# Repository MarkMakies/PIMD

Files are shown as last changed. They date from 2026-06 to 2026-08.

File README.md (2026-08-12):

# PIMD — Pulse Induction Metal Detector

*A from-scratch, multi-band pulse-induction metal detector built for autonomous, position-tagged ground survey.*

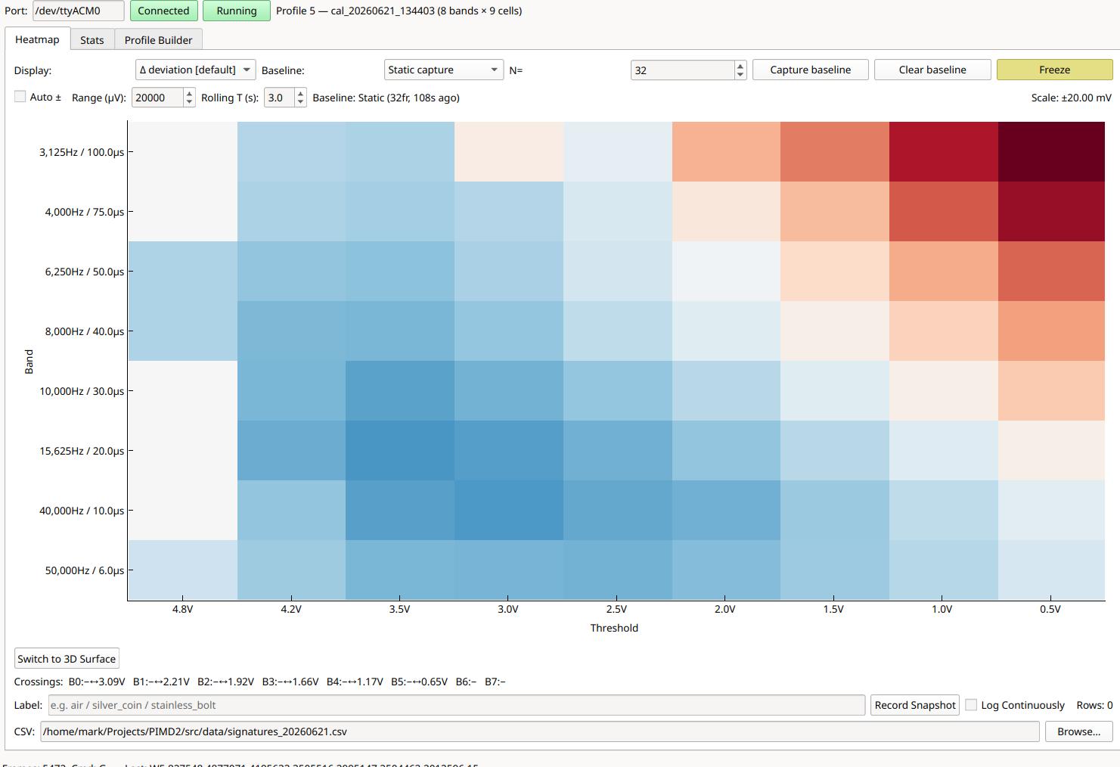
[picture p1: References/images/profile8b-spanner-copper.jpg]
Mixed ferrous + non-ferrous target — the 8×9 decay-space matrix splits into non-ferrous (blue, early decay) and ferrous (red, late decay)


> Above: a single live frame with a steel spanner **and** a copper pipe under the coil. The two
> materials separate *spatially* inside the decay-space matrix — non-ferrous (blue) collapses early,
> ferrous (red) persists late. Getting that separation out of a pulse-induction detector is the whole point.

**Up to date Build diary:** <https://makies.com.au/pulse-induction-metal-detector/>

---

## What it is

A pulse-induction (PI) metal detector designed and built from scratch since November 2023 by a maker
with no prior analogue-electronics background. It is **not** a clone — several design choices are
deliberately unconventional.

In the language of the field, it's a **low-cost, monostatic time-domain electromagnetic (TEM)
spectrometer doing cued interrogation** — though it started life as nothing more ambitious than
"let's build a metal detector with no experience." It is one payload of a larger system: the coil is
towed on a trailer behind **Roverling**, an autonomous RTK-GPS ground robot, so every detection event
can be tagged with centimetre-level position and streamed back over LoRa. It therefore has to be
*quiet, stable and remotely controllable*, not merely sensitive.

What makes it unusual among PI detectors is that it doesn't optimise a single operating point.
It cycles through a user-defined grid of operating points and reports, for every frame, a
two-dimensional **decay-space matrix** — frequency/pulse-width on one axis, decay-amplitude (time) on
the other — that is designed from the ground up as an input to a classifier.

## How it works (in brief)

A high-current pulse energises the TX coil; on hard cutoff the collapsing field produces a flyback
and then a decaying eddy-current response. A nearby target perturbs that decay. The conditioned RX
signal is sampled at precise, calibrated delays.

- **Mode 1** — a single filtered (32-bit) sample at one held delay: the low-noise telemetry path, used for baselines and field tests.
- **Mode 2** — an interleaved sweep across a profile of *(frequency, pulse-width, sample-delay)* points, reported as one frame per sweep. The grid is not fixed by the hardware, and it has deliberately *narrowed* as the corpus taught which cells earn their place. The July 2026 signature corpus was captured on a **63-cell** grid (7 pulse widths × 9 delays, spaced geometrically 9 → 100 µs at ×1.5 per step). The **current profile, `cal_2x11_v5`, runs 2 pulse widths (10 and 100 µs) × 11 sample delays = a 22-cell matrix**, sweeping at **16.1 Hz** *(measured)* — ~30% faster frames for the loss of the redundant middle bands. It is **not yet locked and has no corpus behind it**. Repetition rates are chosen to hold duty near 30%; the 100 µs band runs at 3.125 kHz and **requires the cooling fan** (see Hardware).
- Sample delays use **two anchoring schemes in one profile**, where a PI profile conventionally picks one. Early cells are **amplitude-anchored** to a ladder of voltages (**2.4 V → 125 mV**) high on the flyback decay rather than the usual bottom ~700 mV — that region carries the most discrimination information, and it is where target *polarity* separates the families. Late cells are **time-anchored** on a geometric ladder out along the tail, because past the front end's lobe both families read positive and only *decay rate* separates them. Every delay is snapped to the 8 ns PWM grid (off-grid requests are silently rounded by the hardware). The profile spans the decay from 2.4 V down to the ~110 mV pedestal with no gaps — the null minimum is sampled deliberately, not avoided.
- **Polarity convention:** ferrous targets read **positive** (stored magnetic energy reinforces the decay); non-ferrous read **negative** (opposing eddy currents weaken it). A third class turns out to be common in practice: **crossover targets** (cast iron, some stainless, real jewelry with steel fittings) read negative at short pulses and positive at long ones — the pulse-width axis resolves what a single operating point would misclassify.

## Highlights

- A multi-band decay-space matrix recovering **multi-time-constant discrimination from a PI platform** — something most commercial PI detectors don't attempt.
- **Validated on a 17-target labelled corpus** (July 2026): signature *shape* is invariant with target distance (5–15 cm, 30× amplitude range) and repeats across sessions and recalibrations to within a few percent — the property the classification layer is built on.
- Targets fall into **three shape families** — ferrous, non-ferrous, and crossover — and overlapping targets combine **linearly** (a spanner + copper pipe frame decomposes back into its parts at 0.99 correlation), so unmixing is on the table, not just classification.
- Phase-locked TX/sample timing on one RP2040 PWM slice — **~5 ns sample-trigger jitter (measured)**.
- LTC2508-32 dual-output front end (filtered 32-bit + raw 14-bit no-latency).
- A dedicated delay-calibration tool that measures the clip-release point per band and exports calibrated profiles.
- Three PyQt6 desktop tools: live Mode 1 GUI, the Mode 2 heatmap + ML-data bridge (`ClassViz`, including a self-describing session recorder for training data), and the delay calibrator.
- Built for autonomous use: RTK-GPS position tagging, LoRa telemetry, single dedicated low-noise supply.

## Repository layout

```
README.md                  This file — start here
DESIGN.md                  Full engineering reference (hardware, firmware, protocol, test log)
CHANGELOG.md               Project change log
CLAUDE.md                  Contributor / agent conventions (version bumps, changelog discipline)

mcu/                       MicroPython firmware for the RP2040-Zero
  pimd_mcu.py  main.py

src/                       PC-side tools (PyQt6)
  pimd_gui.py              Mode 1 filtered-telemetry GUI
  pimd_classviz.py         Mode 2 decay-space heatmap + ML logger
  pimd_delaycal.py         Delay-calibration sweep tool
  pimd_rawlog.py           Raw Mode 2 session logger
  pimd_pack.py             Shared 6S pack fuel-gauge maths (imported by the four GUI apps)
  pimd_shape.py            Shared feature maths (family / crossing / decay persistence)
  pimd_features.py         Training-corpus builder
  pimd_target_check.py     Target-registry validator
  pimd_corpus_check.py     Corpus-level acceptance checker
  requirements.txt
  data/                    Settings, captured CSVs and calibrated profiles (runtime-generated)

Electronics/PIMD604/       KiCad project — schematic rev 6.04 (as-built)

References/                Schematic export, scope captures, sample heatmaps
```

## Toolchain & workflow

The firmware is the measurement primitive; every PC tool is a client of the same USB-serial
protocol (`DESIGN.md` §9). Together they form one pipeline:

```
mcu/pimd_mcu.py (RP2040)            — the measurement primitive
      │  USB-serial, ASCII records (DESIGN §9)
      ├─► src/pimd_delaycal.py      — calibrates sample delays,
      │        exports cal_*.json profiles ──► src/data/profiles/
      ├─► src/pimd_gui.py           — Mode 1 live telemetry / bench monitor
      ├─► src/pimd_rawlog.py        — verbatim Mode 2 session logger (ground truth)
      └─► src/pimd_classviz.py      — Mode 2 heatmap; loads & runs saved profiles;
               │    captures signatures ──► src/data/corpora/ + src/data/sessions/
               └─ uses src/pimd_shape.py — shared feature maths
                            │
                            ▼
          src/pimd_features.py + src/pimd_target_check.py
               — registry-validated training-corpus builder ──► ML corpus
```

`pimd_pack.py` is shared by all four GUI apps, so they can never disagree about the same battery.

**Typical workflow**

1. Flash the firmware once (`DESIGN.md` §16).
2. Run **delaycal** after a full thermal soak to produce a calibrated profile; lock the profile JSON.
3. Run **classviz**, *Load & Run* the locked profile, and capture target signatures against the
   target registry in `src/data/targets/`.
4. Build the corpus with **features**; gate a capture day with **corpus_check**.

**gui** is the independent Mode 1 bench monitor used for noise-floor and drift investigation at a
single operating point. **rawlog** is the deliberately dumb recorder: it writes every line the
firmware sends, verbatim, so there is always a raw record no display logic can corrupt. Never run
Mode 1 and Mode 2 at once — always send `E` between mode switches.

> Each tool carries its own detailed operating notes — intent, wire commands used, record formats
> and per-version lineage — in its **file header**, which is updated in the same edit that changes
> the behaviour. Current firmware and tool versions, and the operating profile in use, are on the
> header line at the top of **`DESIGN.md`**; they are deliberately not duplicated here.

## Quick start

No build step for either the PC tools or the firmware.

### PC tools

```bash
python3 -m venv .venv && source .venv/bin/activate
pip install -r src/requirements.txt
cd src
python pimd_gui.py        # Mode 1 GUI (filtered telemetry)
python pimd_classviz.py   # Mode 2 decay-space visualiser + ML bridge
python pimd_delaycal.py   # delay-calibration sweep
```

The tools connect to the board on `/dev/ttyACMx` at 115200 baud.

### Firmware

```bash
# No build step — copy onto the board, then power-cycle it.
.venv/bin/mpremote connect /dev/ttyACM0 fs cp mcu/pimd_mcu.py :pimd_mcu.py + fs cp mcu/main.py :main.py
# (mpremote reset does not re-enumerate USB reliably — power-cycle the board.)
.venv/bin/mpremote connect /dev/ttyACM0 repl
```

### Bench-test over a serial terminal (115200)

```
V                              identify / firmware version
L                              list profiles
Q5   then  G                   Mode 2: stream the loaded operating profile (W5 records);  E to stop
*5000,40000,8400,256  then S   Mode 1: stream (* records, ~20/s);  E to stop
A32                            one 32-sample boxcar average (R record)
```

> Protocol note (firmware v4.23+): the `*` command takes **freq in Hz, pulse/delay in ns**; the `D`
> dynamic-profile command takes **µs**. See `DESIGN.md` §9 for the full contract.

## Hardware

- **Schematic:** the published KiCad project is **rev 6.04**, which represents the board **as-built**. The PCB itself was fabricated from rev **6.01**; 6.04 captures the corrections — there were a few PCB issues that needed rectifying after manufacture.
- **Front end / drive:** functional but a known rework target — a future revision will replace the TX switch and gate driver (planned: STP10NM60N + TC4420/TC4429) to retire the current FET being run past its rated SOA.
- **Thermal:** a thermistor is now fitted to the TX damping resistor. Thermal drift settles to effectively zero once the resistor reaches ~80 °C, which is the dominant warm-up transient.

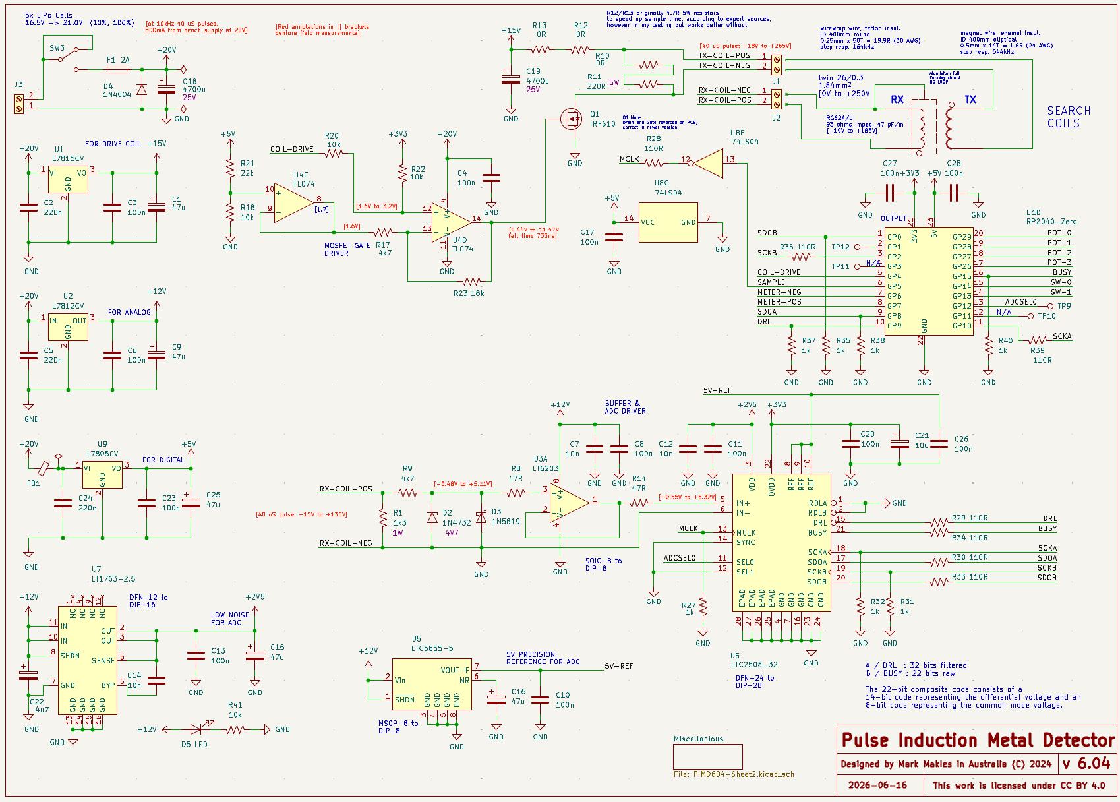
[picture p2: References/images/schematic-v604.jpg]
Schematic — PIMD rev 6.04


## Roadmap

This release is **Phase 2 — publish the work to date.** Active and planned work:

- **Phase 3 — machine learning.** Use the decay-space matrix for filtering, classification and (the stretch goal) ground discrimination. First milestone reached (July 2026): a locked, delay-calibrated operating profile and a 17-target labelled signature corpus recorded at three distances, with distance-invariance, cross-session repeatability and mixture linearity all verified in air.
- **Faster response.** First cut made (August 2026): 63 cells → 22, for ~30% faster sweeps. Because the corpus says different targets go redundant in *different* cells, the narrowed grid has to earn its keep against a fresh corpus before it can be locked — that re-validation is the open work, along with per-cell averaging.
- **Front-end revision** (TX switch + gate driver, as above), plus a scope measurement of TX coil current vs pulse width to settle whether the longest band is past the coil-current plateau.

See **DESIGN.md §14** for the full open-problems list.

## Documentation

- **[DESIGN.md](DESIGN.md)** — the complete engineering reference: measured operating envelope, coils, drive and receive chains, timing, serial protocol, power, invariants and curated test log. Self-contained; a new reader (human or agent) can pick up the project cold from it.
- **Per-app notes** — each tool's intent, operation, wire commands and version lineage live in its own **file header** (`mcu/pimd_mcu.py`, `src/pimd_*.py`); the pipeline that connects them is under *Toolchain & workflow* above.
- **Build diary** — the full chronological story, with photos and dead-ends: <https://makies.com.au/pulse-induction-metal-detector/>
- **Video** — <https://www.youtube.com/@markmakies>

## Licence

This project uses two licences, matched to the kind of work:

- **Code** (`src/`, `mcu/`) — **GNU GPL v3.0-or-later**. See [`LICENSE`](LICENSE).
- **Hardware and documentation** (`Electronics/`, `DESIGN.md`, schematics, images) — **Creative Commons Attribution-ShareAlike 4.0 (CC BY-SA 4.0)**. See [`LICENSE-docs`](LICENSE-docs).

Pulse Induction Metal Detector © 2022–2026 Mark Makies.

## Author

Built by **Mark Makies** (Australia).
Find more work at <https://makies.au/>.

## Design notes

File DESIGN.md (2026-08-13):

# Pulse Induction Metal Detector (PIMD) 

**Author:** Mark Makies (Australia) · **Licence:** CC BY-SA 4.0
**Hardware rev:** 6.04 + shielded enclosure (2026-07-13) + 6S Li-ion supply (2026-07-24) + pack-voltage sense & DS18B20 board temperature (2026-08-07) + **RX front-end +97 mV bias (2026-08-10)** + **U1 L7815CV replaced 2026-08-10 (failed; like-for-like on a larger heatsink)** + **6S pack replaced 2026-08-13 (new balanced cells, same ICR18650-26C arrangement)** + **40 mm 24 V case-mounted extractor fan over the FET / regulator / load-resistor cluster — permanent, pack-fed through the rig's own switch and a fuse, fitted 2026-08-13; supersedes the 38 mm blow-on fan** + **USB and power toroids removed, power cable shortened 27 cm (2026-08-13)** + **C18 2200 µF 35 V fitted 2026-08-14 (was 4700 µF 25 V — voltage derating, not capacitance; C19 assessed and left at 4700 µF 25 V)** · **Firmware:** v4.37 · **PC tools:** gui v4.18 · classviz v1.79 · delaycal v1.49 · rawlog v1.17 · pack v1 · features v15 · shape v1 · target_check v4 · corpus_check v1.10 · **Coil:** v4 · **Operating profile:** `cal_2x11_v5d` (2026-08-13, 2 × 11 = 22 cells, `profile_sha8` **fc7519cd**, **locked and fully measured — no corpus yet**). Bump this line on every edit.
**Last bench update:** 2026-08-13 (40 mm extractor validated — 97.6 min of pulsing over four sessions, 104 618 sweeps, zero flagged rows)
**Doc rev:** 2.9 (2026-08-14) mini consolidation pass (§18), scoped to the C18 refit. **§14.2 (C18 under-rated) is closed** — the 2200 µF 35 V part is fitted, and its "candidate contributor to the 2026-08-10 U1 failure" line is withdrawn as never evidence-backed (`CHANGELOG.md` carries the withdrawal and a better-supported explanation; do not revive it). The schematic-mismatch item renumbers to **§14.2** and gains a third instance for C18, so it is no longer confined to the RX front end; §7 and §15's `§14.3` cross-refs follow it. §14 is down to **two** open problems. Also new in `CHANGELOG.md`, deliberately not promoted here because it is calculated rather than measured: **TX inductance has never been measured**, and the C18/C19 sizing rests on an inferred ≈200 µH. No firmware or tool version changed (2.8)

> This file is self-contained: a new reader — human or AI agent — should be able to pick up the
> project cold from here alone. Empirically measured values are marked *(measured)*; everything
> else is nominal or design intent. **Detail, rationale and history live in `CHANGELOG.md`** —
> if you want to know *why* something is the way it is, search there, not here.

---

## 1. What this is, and current status

A pulse-induction (PI) metal detector designed and built from scratch since November 2023 by a
maker with no prior analogue-electronics background. It is not a clone; several choices are
deliberately unconventional.

The detector is one payload of a larger system: it is towed on a trailer behind **Roverling**, an
autonomous RTK-GPS ground robot, so detection events can be tagged with centimetre-level position
and streamed over LoRa. It therefore has to be quiet, stable and remotely controllable, not merely
sensitive.

**Status — working and field tested.** It discriminates ferrous from
non-ferrous targets in real soil, reliably to ~20 cm before the noise floor dominates.
**Mode 1 (filtered)** is mature and was used for all baselines and field tests. **Mode 2 (raw
profile sweep)** — the decay-curve — is operational and is where all current work
sits. 

---

## 2. Operating principle

A short, high-current pulse is driven through the TX coil, building a magnetic field. The drive FET
is switched off hard; the collapsing field induces a large flyback then a decaying eddy-current
response. A nearby metal target sustains its own eddy currents, perturbing the decay. Sampling the
RX-coil voltage at a precise short delay after turn-off and comparing to a baseline reveals the
target's presence and type. **Turn-off speed and sample-timing precision set the floor on what can
be detected.**

**Target polarity (measured convention):** ferrous → **positive** spike (stored magnetic energy
reinforces the decay field); non-ferrous → **negative** spike (opposing eddy currents weaken it).

**1 — Early: polarity.** Before the front end's negative lobe, sign splits the families. On the
100 µs band that window is **sd 7.97–12.30 µs**, widest at 9.57 µs — steel **+46.5 mV**, copper
**−74.4 mV** against air.  The crossing where a non-ferrous target stops reading negative and starts
reading positive **marches earlier with shorter pulse** — brass crosses at **~12.3 µs** on the 50 µs 
band and **~11.7 µs** on the 10 µs.

**2 — Through the null.** **Both families read positive against air**,
because air is the thing that dips and both targets fill the dip in. Sign is useless there; depth
is the measurement. 

**3 — Late: decay rate.** Out on the pedestal both families read positive and only decay rate
separates them (copper outlasts steel, crossing at ~44 µs on the coil and ~77 µs at 60 mm — the
crossover moves with coupling). A ferrous target adds a genuine **second, slow pole** of its own
that air and non-ferrous do not have.

---

## 3. Measured operating envelope (updated 2026-08-13)

- **Flyback** *(measured, 10 kHz / 40 µs)*: TX coil **−18 V to +265 V**, RX coil
  **−15 V to +135 V**. Gate turn-off **11.47 V → 0.44 V in 733 ns**.
- **FET Q1 limits:** < 10 A, < 300 µs, < 2 % duty. The detector runs above the duty limit and needs redesign.
- **RX front-end node** after R9: **−0.48 / +5.11 V**; ADC input settles
  **~5.0 V**; edge ring peaks **+5.30 / −0.69 V** (brief, current-limited, harmless).
- **Post-bias, air never goes below 67.2 mV** *(measured 2026-08-10, worst case = 100 µs band)*
  against the amplifier's 2.441 mV output floor, all three bands, now has ≥ 65 mV of headroom underneath it.
- **Sample-timing precision** ≈ **5 ns** *(measured)*.
- **Thermal drift** ≈ **−50 µV/s** at 10 kHz / 20 µs *(measured)*. 
- **Noise floor ≈ 38 µV** *(measured 2026-08-13, `cal_2x11_v5`, 32 × 256 averaging, detrended
  32-sweep σ, 40 mm extractor)* — flat across every null/pedestal cell and **independent of delay**,
  i.e. **~64× below** the 2.441 mV amplifier output floor. Band 0's largest cell remains ~2× noisier
  than band 1's at the same amplitude (70 vs 36 ppm raw) — still unexplained, but improved from
  93 vs 38. Noise does **not** rise as the pack falls. *(Supersedes ≈ 65 µV / 93 vs 38 ppm, which
  was the same statistic on the 38 mm blow-on fan — that figure is epoch-bound to ≤ 2026-08-12.)*
- **Run-to-run repeatability** *(measured 2026-08-13)*: the settled band-0 operating point reproduces
  to **0.06 %** across independent cold starts, and bucket-to-bucket noise scatter is **2.2 µV**
  against 6.4 µV on the 38 mm rig.
- **Warm-up from cold: allow 6 min** *(measured 2026-08-13, 40 mm extractor, two independent cold
  starts)*. Band-0 mean settles as a **clean single exponential**, τ = **1.15 / 0.90 min**
  (r² = 0.982 / 0.988), within **0.2 % at 5.6 / 3.8 min**. The DS18B20 still reaches its final
  reading well before the signal settles and **is not a readiness indicator**. *(Supersedes the
  10 min / τ = 2.15 min figure, epoch-bound to the 38 mm fan, where warm-up was **two-stage** — a
  fast drop then a slow case-soak still drifting at 20–25 min. Continuous bulk air exchange
  suppresses the slow stage; that shape change is the mechanism.)*
- **Standard Operating Conditions:** Mode 1 · 10.0 kHz / 20.0 µs pulse / 10.0 µs delay /
  DS 256 · coil in air, no targets. Reference capture:
  `References/images/GUI-steady-state-256-1024.jpg`.
- **Board temperature moves the operating point — but the DS18B20 does not predict it** *(measured
  2026-08-12)*. At the **same indicated 44.1 °C** band-0 mean read 543.8 and 533.9 mV five minutes
  apart: **1.8 % spread at identical sensor temperature**. Bulk warm-up and airflow changes move
  band 0 in **opposite directions** against the same sensor — nudging the fan off the U1/FET cluster
  took the sensor 41.0 → 46.0 °C and band 0 **+3.7 %**, where warm-up over that span moves it down.
  A single µV/°C referred to this sensor is therefore **not well defined**. Which component dominates
  is **not determinable from the logs** — it needs a thermocouple on U1/Q1.
- **The fan mount was measurement-critical — resolved 2026-08-13 by the permanent case mount.** On
  the loose 38 mm fan a slight nudge was worth **3.7 % on band 0**, more than the entire discharge
  range. The 3.7 % still stands as the measure of how hard cooling moves the operating point (and
  is what 17.14's sign test detects), but fan geometry is now a fixed property of the build and no
  longer a variable to control.
- **The DS18B20 reads ~8 °C hotter on the extractor** — plateau **47.8 °C** against **39.8 °C** on
  the 38 mm blow-on, from comparable cold starts, because the sensor sits on the load resistor and
  has lost the old fan's direct impingement. **Board temperatures either side of 2026-08-13 are
  different quantities and must not be compared.** It remains blind to the regulator die.
- **State of charge barely reaches the operating point** *(measured 2026-08-12, at flat board
  temperature, two windows spanning 23.05 → 19.07 V)*: **~1 mV/V grid mean** (0.17–0.23 %/V), one
  sign. Total movement across a full 2.1 V discharge window is **−0.69 %** grid mean / −0.81 % band 0
  / −0.54 % band 1. **Thermal drift dominates supply drift by ~10×.**
- **Full-scale headroom:** the coldest capture of 2026-08-12 was **3633 mV at 19.5 °C** on a full
  pack — the day's maximum on any cell, **1367 mV (27 %) below** the 5.000 V full scale. Nothing
  railed or floored in 3.1 h of pulsing. **Untested below 19 °C.**

---

## 4. System block diagram (text)

```
 6S Li-ion (19.8–25.2 V, working floor 19.0 V)
        │  F1 2A ─ D4 reverse-prot ─ FB1 ──► `+20V` rail (raw pack, after fuse + toroid — feeds
        │                                     the three linear regs below and GPIO26's divider)
        ├── U1 L7815CV ──► +15 V  (coil drive rail)
        ├── U2 L7812CV ──► +12 V  (analogue rail)
        ├── U9 L7805CV ──► +5 V   (digital) ──► RP2040 onboard LDO ──► +3V3
        └── U7 LT1762-2.5 ──► +2V5 (ADC)        U5 LTC6655-5 ──► +5V precision ref

 RP2040-Zero (U10)
   GPIO4  PWM2A ─ COIL-DRIVE ─► U4C/U4D gate driver ─► Q1 (IRF610) ─► TX coil
   GPIO5  PWM2B ─ SAMPLE/MCLK ───────────────────────────► LTC2508 conversion start
   (GPIO4 & GPIO5 share PWM slice 2 → phase-locked TX pulse & sample trigger)
   GPIO26 pack-voltage sense (22k/2.7k divider)   GPIO6 DS18B20 board temperature

 TX coil ──(flyback, resistive damping ~220R)
 RX coil ─► R1 damp (1.5k‖10k=1304Ω) ║ R9 4.7k series ─► clamp (D2 4.7V zener + D3 1N5819) ─► 47R
          ─► LT6203 preamp/ADC driver (U3, single +12V) ─► LTC2508-32 ADC (U6)
          ─SPI─► RP2040
                       SDOA/SCKA/DRL  = 32-bit filtered/decimated  (SPI1, Mode 1)
                       SDOB/SCKB/BUSY = no-latency raw 14-bit       (SPI0, Mode 2)

 RP2040 ─ serial (USB-CDC / UART) ─► PC tools (PyQt6)
```

---

## 5. Coils

Separate TX and RX windings (a two-winding "transformer", **not** a shared mono coil).

**Coil v4:** both coils slotted into 12 mm Perspex, RX shielded with copper tape, both embedded for
mechanical stability (earlier coils shifted under rover vibration and drifted). Faraday shield on
RX with **no closed loop**.

- **TX** 520 × 360 mm, 10 turns 0.5 mm (24 AWG) enamelled, **17.6 m**, 1.7 Ω
- **RX** 430 × 265 mm, 50 turns 0.25 mm (30 AWG) Teflon silver-plated wire-wrap, **≈ 69.5 m**,
  22.9 Ω
- Cable: RG62A/U coax (93 Ω, 47 pF/ft) + twin 26/0.3

**Damping is intentionally biased toward over-damping** — it kills ring faster and lets sampling
start earlier, trading a little amplitude for earlier access to the decay. Tuned empirically on a
scope, not by formula.

---

## 6. Transmit / drive chain

- **Q1:** IRF610 N-channel MOSFET, low-side switch, source to GND. Schematic limits < 10 A /
  < 300 µs / < 2 % duty; the 200 V rating is marginal against measured flyback and is managed by
  duty limits + damping (§14.1).
- **Gate driver:** U4C → U4D (TL074 sections) level-shift the 3.3 V `COIL-DRIVE` logic to a ~10 V
  gate swing. Design intent: fast, non-linear FET switching with parasitic-capacitance management.
- **Gate / damping network:** R12/R13 are now **0 Ω** (originally 4.7 Ω 5 W to slow the gate edge
  for SOA; this build performs better without them).
- **Turn-off** *(measured, 10 kHz / 40 µs)*: gate **11.47 V → 0.44 V in 733 ns**.

---

## 7. Receive / acquisition chain

### RX front end (schematic v6.04)

```
RX coil ─┬─ R1 ─ GND                   (shunt = damping; AS BUILT 1.5k ‖ 10k = 1304Ω,
         │                              schematic v6.04 still draws a single 1.3k — §14.2)
         └─ R9 4.7k ──┬─ D2 1N4732 (4.7V zener) ─┐  (positive clamp)
                      │  D3 1N5819 (Schottky) ───┘  (negative clamp)
                      └─ 47R ─┬─► U3A LT6203 +input, pin 3 (single +12V supply)
                              │
    U5 pin 7 (5V-REF) ─[240k 1% metal film]─┘   +97 mV bias — fitted 2026-08-10, NOT on the
                                                schematic (§14.2)
```

- **R1 (shunt) is the RX damping resistor**, which also cleans up TX via mutual coupling.
   **As built it is TWO resistors in parallel, and the schematic does not show this**:
  **1.5 kΩ ∥ 10 kΩ**  **1304 Ω effective**. Schematic v6.04 still draws a single `R1 1.3k`. 
  By that fit the network sits at **ζ = 1.06 — just into over-damping**, which is the intent.
- **R9 = 4.7k (series) is clamp current-limit only**, not damping.
- **D2 / D3** sit in series across the post-R9 node and conduct only outside ~0–5 V; between the
  rails the diodes are off and R1 does the damping.
- **47 Ω** between LT6203 output and ADC input limits over-range current into the ADC's protection.

### Preamp / ADC / references

- **U3 LT6203** dual high-speed op-amp, single +12 V.
- **U6 LTC2508-32**, 32-bit oversampling SAR with a configurable decimation filter **and** a
  no-latency raw output:
  - **SDOA (SPI1):** 32-bit filtered/decimated, `DRL` data-ready-low — the precision path.
  - **SDOB (SPI0):** no-latency raw 14-bit the acquisition path.
  - **Decimation** SEL0 (GPIO12): 256 (operating) or 1024.
  - **Conversion sync:** the falling edge of GPIO5 (`SAMPLE`/`MCLK`) starts each conversion, so
    every TX cycle yields one timed sample at exactly `sample_delay` after coil turn-off.
- **References:** U5 LTC6655-5 (precision 5 V), U7 LT1762-2.5 (low-noise 2.5 V for ADC).

### Acquisition architecture (decided)

Use the **raw no-latency path (SDOB)**, not the filtered one. At 5 kHz the filtered path has
≈ 0.46 s group delay, ≈ 0.5 s settling after any delay change and only ≈ 2.4 Hz bandwidth —
unusable for sweeping the sample point. Recover resolution by **boxcar-averaging M raw samples at a
held delay** (noise ∝ 1/√M; M = 16 ≈ 350 µV in ~3.2 ms, matching the filtered path's real-world
450 µV floor). The 32-bit precision is otherwise wasted: measured noise is ~500× the converter's
own 0.95 µV floor — **the front end dominates.**

**BUSY edge sync is required for accurate SDOB reads** : wait for BUSY-high (conversion
starts), then BUSY-low (complete), then read SDOB. Without it, reads landing mid-conversion produce
bit-truncated outliers at exactly **1/4 and 1/2** of the true value. Side effect: the BUSY-high
pulse at 10 kHz is ≈ 15 µs and MicroPython's polling loop catches ≈ 1-in-6, reducing effective raw
sample rate to ≈ 1.6 kHz. Accepted trade for accuracy.

**Clip-release** — the instant the conditioned signal leaves the clamp rail (~4.7 V) and enters the
linear 0–5 V window — is the true earliest-valid sample time. `pimd_delaycal.py` measures it
directly.

### The front-end transient — measured at the amplifier input

**Shape — from the 2026-08-08 fit, and the shape is what survives:**

- **Two real poles with opposite-sign residues**, `V = A·e^(−t/τf) − B·e^(−t/τs) + V_q`:
  **τ_fast = 1.125 µs, τ_slow = 2.270 µs** *(measured)*, fit RMS 0.87 mV over 894 points. Exactly
  **one zero crossing** — it is not ringing.
- **ζ = 1.06 — mildly over-damped**, not critically damped. 
- **The negative lobe is real, it is in air, and it is on every band.** It is **not** amplifier
  overload recovery: it is present *before* the LT6203, and it **responds to metal** — a steel
  spanner on the coil removes the zero crossing entirely (minimum +15.5 mV, difference up to
  +48.9 mV). 

### The +97 mV bias mod — built and characterised *(2026-08-10)*

**The problem it solves.** U3A is a unity-gain follower on a single +12 V rail and its output cannot
go below **2.441 mV**, so air's excursion below quiescent was clipped flat. 

**The fix is one resistor** 240 k 1 % metal film from U5 pin 7
(5V-REF) to U3A pin 3. Pin 3's DC path to ground is `R8 + R9 + RX coil` ≈ **4.77 kΩ** (the coil's
19.9 Ω shorts out R1, so R1 barely features), giving 5.0 × 4770/244770 = **97.4 mV**. Taken from
5V-REF rather than +5 V or +12 V so that offset and full scale drift together and the code does not
move. Signal-node loading is **1.9 %**.

### Target decay — model fits over the measured window *(2026-08-10, fitted in log space)*

**Air and brass need only a single repeated pole** — the free two-pole fit drives τ_fast → τ_slow,
and `(P + Q·t)·e^(−t/τ)` fits identically well. **Steel on the two long bands needs a genuine
second, slow pole, and that is the target's own eddy decay:**

| band | air | brass | steel |
|---|---|---|---|
| 100 µs | τ 1.96 µs · ±5.6 mV | τ 1.79 µs · ±8.5 mV | τf 1.24, **τs 19.0 µs** · ±6.0 mV |
| 50 µs | τ 1.89 µs · ±6.8 mV | τ 1.77 µs · ±8.4 mV | τf 1.18, **τs 23.4 µs** · ±8.7 mV |
| 10 µs | τ 1.78 µs · ±13.4 mV | τ 1.76 µs · ±13.2 mV | τ 1.67 µs · ±12.4 mV |

**The slow pole appears only with a ferrous target and vanishes on the 10 µs band** — a 10 µs pulse
barely excites it. Independently corroborated by the fill fractions, where steel filled only 62 % of
the null at 10 µs against 100 % on both long bands (§2). *Caveat on the fast pole: every capture
starts at ~9–12 µs, so a ~1.2 µs pole is far outside the data and **τ_fast is not independently
identifiable here** — treat it as a fitted shape parameter, not a measurement.*
`References/images/bias_mod_delay_plot_20260810.png` overlays these fits on the traces.

### RX L and C — pinned *(2026-08-08)*

**ζ is the one number here that does not depend on R at all.** For a parallel RLC the two fitted
poles alone fix it:

> **ζ = (τ_f + τ_s) / (2 √(τ_f · τ_s)) = 1.0622**

Taking the fitted poles with R1 = 1300 Ω gives **C = 579 pF**, **L = 4.41 mH**, √(L/C) = 2762 Ω and
**R_crit = ½√(L/C) = 1381 Ω**. 

**Substitution sensitivity** — what happens if R1 is *changed*, holding the fitted L and C. Damping
is a **shunt**, so **lower R means more damping**. (Unlike ζ above, this table inherits the R = 1300
assumption through L and C, so read it as a guide to picking a resistor, not as a measurement.)

| R1 | ζ | |
|---|---|---|
| 1239 Ω — as-built pair, −5 % corner | 1.11 | over-damped |
| **1304 Ω — as built, nominal (1.5k ∥ 10k)** | **1.06** | **over-damped, the intent** |
| 1370 Ω — as-built pair, +5 % corner | **1.01** | over-damped, but **effectively critical** |
| 1380 Ω | 1.00 | critical |
| 1400 Ω | 0.99 | under-damped — ring returns |

**These values rest on the 2026-08-08 scope fit alone** — 894 points, residual RMS 0.87 mV, taken
at the amplifier input on the current hardware. 

---

## 8. Digital / timing (RP2040)

- **MCU:** Waveshare RP2040-Zero (U10), MicroPython. Firmware `mcu/pimd_mcu.py` **v4.37**.
- **Pulse + sample generation:** two PWM channels on the **same slice** (GPIO4 = PWM2A drive,
  GPIO5 = PWM2B sample). Same slice ⇒ both rising edges align at period start; drive falls at
  `pulse_width`, sample falls at `pulse_width + sample_delay`. **This phase-locking is the core
  timing mechanism — never split these onto different slices**. Timing precision ≈ 5 ns
  *(measured)*.
- **Pulse width** 5–100 µs typical. **Sample delay** software-set, with an
  empirical `SAMPLE_PULSE_CORRECTION = 0.904 µs` offset between the PWM edge and the ADC trigger.
  Every delay the hardware can produce is a multiple of the **8 ns PWM grid**; an off-grid request
  is silently rounded. **8 ns is also the hard minimum spacing between two cells** — the `dd`/`sd`
  CC-write skip means two cells closer than that collapse silently into one.
- **Pulse rate** 2–50 kHz. A **prime-ish** rate halved noise by avoiding beat frequencies — the
  choice is deliberate. **Known-bad rate: 31.25 kHz** 
- **Board temperature: DS18B20 on GP6.** 1-Wire, SKIP ROM, CRC-checked, 30 s cadence,
  3V3 normal 3-wire mode.
- **SPI map:** SPI0 raw (SCKB GPIO2 / SDOB GPIO0 / BUSY GPIO15); SPI1 filtered (SCKA GPIO10 /
  SDOA GPIO8 / DRL GPIO9); SEL0 = GPIO12.

---

## 9. Serial protocol (both modes) — the firmware↔tooling contract

Two **mutually exclusive** acquisition modes over one serial link (115200 baud). Starting one
requires `E` first. *(Literal field separator is `", "` — comma-space — shown comma-only below;
parsers tolerate either. All timing fields are exact integers: freq in Hz, pulse and delay in ns —
**except the `D` command below, whose `pulse` and per-cell delays are in µs.**)*

**Mode 1 — filtered / interrupt-driven** (mature; all baselines & field tests):
- **in:** `S`/`s` start · `E`/`e` stop · `*<freq_hz>,<pulse_ns>,<delay_ns>,<downsample>` configure
- **out:** `*<time_ms>,<value_uV>,<stddev_uV>,<freq_hz>,<pulse_ns>,<delay_ns>,<downsample>`
- **rate:** pulse_freq / downsample (~20/s at 5 kHz / 256)

**Mode 2 — raw interleaved moving-average sweep** (the active path):
- **in:** `Q<n>` select profile · `G`/`g` start streaming · `E`/`e` stop ·
  `D<avg>;<freq_hz>,<pulse_us>,<d0>,…;…` define the RAM-only dynamic profile (index 5).
  **`avg` is bounded 1..128**; the whole `D` is refused on any invalid cell, and a
  refused `D` leaves the previous dynamic profile live — **wait for `D OK`** (§8).
- **out:** `W<profile_idx>,<time_ms>,<mean_ch0>,<mean_ch1>,...`
- **rate:** one W record per full sweep, rate-limited to one per `MIN_EMIT_MS = 10` ms (never
  reached in practice). Each cell gets one PWM period per sweep, with a rolling average `averages`
  deep held *across* sweeps — so emitted rate **is** sweep rate. `S` is rejected while Mode 2 runs.

**Both modes:**
- `V`/`v`/`?` identify →
  `V<fw>,<board_id>,<num_profiles>,<active_idx>,<freq_hz>,<pulse_ns>,<delay_ns>,<downsample>,<pack_mV>,<board_temp_dC>,<lockout>`
  — **11 fields since v4.28**; the trailing three are sensor/lockout state. `board_temp_dC` is
  deci-degrees C and **`-32768` means NO READING**, never a temperature. **Consumers must treat the
  reply as extensible.**
- `P<time_ms>,<pack_mV>,<board_temp_dC>` — **unsolicited** sensor telemetry, ~60 s cadence
  *(v4.28+)*. **Parsers must anchor on a digit after `P`**: `PACK:` and `LOCKOUT:` are
  human-readable firmware messages on the same wire, and matching `P` alone swallows them.
- `L` list profiles → one `L<idx>,<freq_hz>,<n_bands>,<n_cells>,<averages>,<name>` per profile
- `A<n>` raw boxcar average (idle / Mode 1 only) →
  `R<time_ms>,<mean_uV>,<std_uV>,<count>,<freq_hz>,<pulse_ns>,<delay_ns>,<min_uV>,<max_uV>`
- `B` diagnostic counters, **reset-on-read** — **9 fields** →
  `B<busy_high_count>,<overrun_count>,<emit_block_count>,<emit_block_ms_max>,<gate_reject_count>,`
  `<gate_reprime_count>,<busy_timeout_count>,<busy_spin_min_left>,<rail_absent_ms_max>`. The last
  three arrived with the v4.37 rail-loss abort: `busy_timeout_count` says whether a rail loss
  happened at all, `busy_spin_min_left` is how close a *healthy* spin came to `BUSY_SPIN_LIMIT`
  (it resets to the limit, not to 0, so a small value means the cap is too tight), and
  `rail_absent_ms_max` is the longest rail-absent rest. No parser exists in `src/` — read by a
  human over a serial terminal.
  **The ratio is the number to read:** rejections with near-zero re-primes means the outlier gate is
  catching glitches, which is its job; re-primes climbing with the signal means it is fighting real
  signal and `OUTLIER_GATE_FRAC` is too tight for the profile in use (§8).
- `E` is the universal stop. Modes are mutually exclusive.

**µV scaling (invariant):** filtered (Mode 1) `raw32 * 5_000_000 // 2**31`; raw (Mode 2 / `A`)
`raw14 * 10_000_000 / 2**14`.

---

## 10. Scan profiles

Profiles are fixed/compiled-in or RAM constants (no flash writes). **Geometry is constant per
profile**.
**Frames from different profile geometries must never be mixed in one dataset.** An identical cell
count does *not* imply comparability — comparability rests entirely on the
`(profile_name, profile_sha8)` guard in `pimd_features`, **which must not be relaxed**.

### Operating profile — `cal_2x11_v5d` (2026-08-13)

#### cal_2x11_v5d — Cell / Zone / Delay / Anchor Table

`profile_sha8` **fc7519cd**. 2 bands × 11 cells (22 cells total), `averages` 32. **The sole profile
in use and the only file in `src/data/profiles/`** — v5, v5a and v5b were removed from the working
tree on 2026-08-13 and live in git history. **Locked, and every voltage in the table below is a
bench reading, not a target.** No corpus has been recorded against it yet.

**Sweep rate: 17.86 Hz** *(measured 2026-08-13, fw v4.37)*, against 12.45 Hz for the retired
`cal_3x10_v5` — **+43 %**. Unchanged across the v5a → v5b → v5d re-cuts, as expected: those moved
delays, never the band count, cell count or averaging depth. The run-length figures likewise carry
forward and are: **3.1 h bench-run on 2026-08-12, zero flagged rows in 63 813 uninterrupted
sweeps**, plus the 2026-08-13 extractor validation below.

**Runs at 3.125 kHz on the 100 µs band, and requires the cooling fan running.** Without the fan,
this band trips the +15 V regulator (U1) on a ~42 s cycle. The fan is powered from the rig's own
switch, so the requirement is **structural, not an operator step** — there is no state in which the
board pulses and the fan does not. **Validated 2026-08-13**: 104 618 sweeps over 97.6 min with zero
flagged rows, including a cold start at 24.48 V (worst U1 corner); the one run that ended did so on
the 19.0 V pack floor, not on heat.

| Cell | Zone | Delay µs (100 µs → 10 µs) | Anchor | Measured mV (100 µs / 10 µs) | Cross-band |
|---|---|---|---|---|---|
| 1 | Early | 9.456 → 6.496 | Amplitude — **4.700 V** | 4680.0 / 4696.0 | 0.34 % |
| 2 | Early | 11.392 → 8.376 | Amplitude — **1.900 V** | 1874.3 / 1898.5 | 1.28 % |
| 3 | Early | 12.136 → 9.088 | Amplitude — **1.150 V** | 1133.2 / 1151.0 | 1.56 % |
| 4 | Early | 13.248 → 10.176 | Amplitude — **0.500 V** | 498.9 / 499.4 | 0.09 % |
| 5 | Early | 15.088 → 11.960 | Amplitude — **0.125 V** | 123.0 / 124.2 | 0.91 % |
| 6 | Mid descent | 15.872 → 12.896 | Time-anchored, band-dependent | 79.0 / 77.9 | 1.32 % |
| 7 | Peak min | 16.920 → 13.800 | Null minimum (band-dependent depth) | 62.5 / 69.9 | 11.32 % |
| 8 | Rising | 21.160 → 16.160 | Rising out of null | 91.8 / 92.0 | 0.24 % |
| 9 | Late | 37.736 → 19.640 | Time-anchored — decay rate, not amplitude | 111.8 / 108.0 | 3.45 % |
| 10 | Late | 67.296 → 23.864 | Time-anchored — decay rate, not amplitude | 112.3 / 109.9 | 2.15 % |
| 11 | Late | 120.000 → 29.000 | Band's longest delay (10 µs band at hardware limit, 96 ns margin) | 112.0 / 111.0 | 0.93 % |

**Measured in air** *(2026-08-13, 1 666 sweeps over 93 s at steady state, zero flagged rows, pack
20.17 V, board 49.4 °C)*. Air std dev is 0.07–0.88 mV per cell on the 100 µs band and 0.05–0.23 mV
on the 10 µs. The cut sits near the **bottom** of the §12 clean window, so the anchors read higher
on a fuller pack — see **17.23**, and note its 2026-08-13 qualifier: the steep early anchors are far
more supply-sensitive than the grid mean. Cell 1 at 4.680 V is 94 % of the 5.000 V full scale and
wants watching at the top of the pack range.

**Zone breakdown:** 5 early / 1 mid descent / 1 peak min / 1 rising / 3 late — 11 cells total per band.

**Spacing is deliberately uneven.** Gaps across the amplitude anchors are 1.936 / 0.744 / 1.112 /
1.840 µs on the 100 µs band and 1.880 / 0.712 / 1.088 / 1.784 µs on the 10 µs — tight through the
knee where the target response turns over, wide either side. Even spacing has no claim here: the
decay is **not log-linear above ~2 V** *(measured 2026-08-13, both bands)*, so equal voltage ratios
are not equal time steps.

**Cross-band matching:** holds for cells 1–5 only (amplitude anchors), and is within 1.6 % on all
five. Cells 6–8 are null-region, band-dependent by construction — cell 7's 11.3 % is the null depth
differing by band, not a defect. Cells 9–11 are time-anchored.

**The null is sampled deliberately at its minimum** (cell 7) 

**`threshold_v` has MIXED MEANING in this profile.** Cells 1–5 carry the **real measured
amplitudes** (4.700 / 1.900 / 1.150 / 0.500 / 0.125 V) and are what `pimd_delaycal` keys its nudge
targets on. Cells 6–11 are **placeholder ordering keys only** (100 / 90 / 80 / 70 / 60 / 50 mV),
chosen solely to keep the column strictly descending. **Do not mine cells 6–11 as voltages** — the
null minimum measures 62.5 / 69.9 mV, not 90.

---

## 11. Invariants — do not break

- **Same-slice PWM phase-locking** (GPIO4/GPIO5, slice 2).
- **serial wire format**, both modes (§9).
- **No scan scheduler or PC-defined logic in firmware** beyond the fixed profile loop.
- **no flash writes** in normal operation (flash writes spike the noise floor ~10×).

---
## 12. Power system

| Rail | Source | Purpose |
|---|---|---|
| +15 V | U1 L7815CV | coil drive |
| +12 V | U2 L7812CV | analogue |
| +5 V | U9 L7805CV | digital |
| +3V3 | RP2040 onboard LDO | MCU/logic |
| +2V5 | U7 LT1762-2.5 | ADC |
| 5 V ref | U5 LTC6655-5 | precision reference |

Input: **6S Li-ion (19.8–25.2 V)** — 18650 cells, ICR18650-26C. F1 2 A, D4 1N4004 reverse
protection, FB1 ferrite bead. A **dedicated** battery powers the detector; the rover's 40 V supply
was too noisy. **More than one pack is in rotation** — packs are swapped as they charge, so no
single stored calibration describes "the" pack (§15, `pimd_pack.py`). **Confirmed 2026-08-12:** the
15 V rail held 15.20 V from 24.69 V down to 19.07 V and the operating point moved **−0.8 % across a
2.1 V pack swing** (§3).

**Measured envelope** *(2026-08-12, full charge → 19.0 V, `cal_2x11_v5`, board at temperature)*.
**Epoch-bound: measured on the pack retired on 2026-08-13**, which was tired and reached its knee
early. The *shape* is expected to carry to a current pack — same cells, same load — but the absolute
figures are not a spec for one, and want re-measuring on a single continuous run-down:

| Parameter | Value |
|---|---|
| Endurance, pulsing | **3.10 h** (186 min), 24.69 → 19.00 V, 4 sessions with 2 long rests |
| Endurance, single continuous run | **83.5 min**, 24.69 → 21.00 V |
| Rest recovery at 21.0 V | **+2.04 V** in 44 min unloaded |
| Discharge rate, loaded | −32.8 mV/min at 23 V, rising to **−72.7 mV/min** over the last 13 min |
| Discharge rate, drive off (lockout latched) | **−30.2 mV/min** — ~58 % of the loaded rate |
| Sag under load | 850 mV at full charge → **2.43 V** at the trip |
| +15 V rail | **15.20–15.21 V, flat to 50 mV** across the whole discharge *(DMM, 4 spot checks)* |
| Pack telemetry vs DMM | agrees to **< 80 mV, typically < 20 mV** (1 LSB = 7.35 mV) |

**Two confirmations on the current pack** *(2026-08-13)*: rest recovery measured **+2.17 V** after a
trip at 19.05 V, consistent with the +2.04 V above; and the **extractor fan is a continuous ~1–2 W
pack load for the whole of any powered session**, since it shares the rig's switch — any re-measure
of the figures above is therefore a fan-on figure and should say so.

**Working floor: 19.0 V — settled, and not a test build.** `PACK_VOLTAGE_TRIP_MV` 19_000 /
`PACK_REARM_MV` 19_500. Introduced as a test floor on 2026-08-12 and **kept** on that day's results:
nothing electrical or measurement-side objects to it. D4 is a shunt clamp with no series drop, so
the L7815 sees the pack directly and keeps ample headroom against the ~17.2 V it needs — the rail
measured flat to 50 mV all the way down — and noise, SNR and railing are unchanged at the bottom of
the range. The trip protects the **cells**, not the rail. The two constants must always move
together; 500 mV is the hysteresis and nothing else depends on the re-arm level. Earlier revisions
of the firmware carried an instruction to restore a 21.0 V floor; that instruction is **withdrawn**
and the source comment now says so.

**State of charge is a runtime fraction, not a cell voltage.** The PC tools read SoC as the fraction
of usable pulsing runtime left against the 19.0 V floor, from a curve of *loaded* terminal volts →
minutes-to-trip, with time remaining fitted live over a trailing window (§15, `pimd_pack.py`). A
resting per-cell open-circuit curve applied to a loaded pack voltage is **not** a valid gauge here
and was withdrawn on 2026-08-13. 

---

## 13. What makes this design unusual (deliberate, validated choices)

- **Sampling high on the flyback decay rather than just the usual bottom ~700 mV.** The early-decay
  region carries the most discrimination information and sits well above the noise floor. This is
  the oldest unconventional choice in the project and it still holds.
- **The profile spans the whole decay with no gaps.** It runs from **2.4 V down to the
  ~110 mV pedestal** in 11 cells, and there is nothing it has to avoid.
- **Two anchoring schemes in one profile — amplitude early, time late.** Conventionally a PI profile
  picks one. Here the early cells are anchored to *voltages* on the decay, because that is where
  target **polarity** separates families; the late cells are anchored to *delays* out on the tail,
  because past the front end's lobe both families read positive and only **decay rate** separates
  them. Using one scheme for both halves would sample the wrong quantity in one of them.

---

## 14. Open problems

1. **Q1 duty headroom.** Present operating points run well above the schematic's < 2 % FET duty
   note; Q1 (IRF610) is being pushed past its noted SOA. A higher-rated replacement is probably
   warranted.

2. **The schematic no longer matches the build in three places.**
   *(a)* **The 240 k bias resistor from 5V-REF to U3A pin 3 is not drawn at all** (RX front end).  
   *(b)* **R1 is two resistors in parallel — 1.5 kΩ ∥ 10 kΩ, 1304 Ω effective — the schematic
   still shows a single 1.3 kΩ** (RX front end).  
   *(c)* **C18 is 2200 µF 35 V as built; the schematic still shows 4700 µF 25 V** (power section,
   refitted 2026-08-14). Note C19 **is** correct as drawn at 4700 µF 25 V and was left alone on
   purpose — it is the pulse reservoir, so changing it would move the `cal_2x11_v5d` anchors.

---

## 15. Repository / file inventory

**One line per file: what it is, not what it has been.** Version history and design rationale live
in `CHANGELOG.md` and in each file's own header lineage.

| Path | Role |
|---|---|
| `mcu/pimd_mcu.py` | RP2040 MicroPython firmware (**v4.37**) — both modes, all profiles, the RAM-only dynamic profile (index 5), pack sense and board temperature. MicroPython **pure-Python only**. |
| `mcu/main.py` | One-line board launcher: `import pimd_mcu` |
| `src/pimd_gui.py` | **v4.18** — Mode 1 filtered-telemetry GUI. Pack SoC / board-temperature gauges; session logs to `data/sessions/gui_<ts>.csv`. |
| `src/pimd_classviz.py` | **v1.79** — Mode 2 signature visualiser and the **corpus-capture workbench**. Four tabs (Heatmap / Stats / Analysis / Family Plane). Loads and runs saved profiles as RAM-only dynamic profiles — **`Load & Run` waits for `D OK`** before selecting or streaming, so a refused profile can never be mis-labelled in the session header (§8). **Marks ADC-railed cells**: a standing `⚠ RAIL: N cells` label in the top bar, a red *Latest* cell with tooltip, and a session mark on each new entry — the value is deliberately **not** filtered or substituted, because a rail is a profile defect to fix at the delay ladder. Auto-logs a self-describing session dump whenever the stream runs; registry-backed structured capture writing `src/data/corpora/`; pack/temperature telemetry written to the dump automatically. Profile *authoring* is not here — it is in delaycal. |
| `src/pimd_delaycal.py` | **v1.49** — delay-calibration sweeper and the only profile author. Coarse+fine two-phase sweep per (freq, pulse) pair, threshold-crossing delays snapped to the 8 ns grid, thermal soak monitoring, auto-nudge, Compare Profiles tab, pack/temperature gauges and a conditions span recorded into every exported profile's notes.  |
| `src/pimd_rawlog.py` | **v1.17** — deliberately dumb raw logger: loads a profile, streams it, writes every firmware line **verbatim** to `data/sessions/rawlog_<ts>.txt`. No tables, no derived values, so it cannot develop display-layer defects.  |
| `src/pimd_shape.py` | **v1** — shared signature-geometry maths (pure NumPy, **no Qt**). `unit_shape` / `amp_l2` / `snr`, `band_means`, `band_range_mean`, `crossing_us`, `decay_persistence`, `family`. Geometry always passed explicitly; bands and thresholds resolved **by value**, never by stored index. `family` (sign) and `decay_persistence` (magnitude) are read together and neither overrules the other. |
| `src/pimd_pack.py` | **v1** — shared pack fuel-gauge maths (pure stdlib, **no Qt**), imported by all four GUIs so they cannot disagree about the same pack. SoC is the fraction of usable pulsing runtime left, from a curve of *loaded* volts → minutes-to-trip, zeroed on `PACK_TRIP_MV` so moving the firmware floor re-zeros the gauge from one constant; only the curve's **shape** reaches the percentage. `PackTracker` fits the discharge rate live over a trailing window for an `H:MM` time-remaining figure, and drops history on a pack swap, a pack-absent/return or a disconnect. `--recal <session csv…>` rebuilds the curve from `# pack_v:` tracks. **The shipped curve is the retired pack's** — regenerate after one continuous run-down. |
| `src/pimd_features.py` | **v15** — session-CSV → training-corpus builder (offline CLI). Registry join, **hard geometry guard: one `(profile_name, profile_sha8)` per corpus build**. Parses the dump's `# pack_v:` / `# soak:` / `# stall:` / `# capture:` / `# mark:` comment tracks; `pack_v_at()` interpolates a voltage per capture. |
| `src/pimd_target_check.py` | **v4** — target-registry loader/validator (CLI + library). `DEFAULT_REGISTRY_PATH` here is the single source of truth for registry location. `-f` is required — there is no default path. |
| `src/pimd_corpus_check.py` | **v1.10** — corpus-level acceptance checker. Shape distance-invariance, split-half SNR, repeat consistency, falloff fit. One flat PASS/AMBER/FAIL/SKIP table, exit 1 on any FAIL, so it can gate a capture day. |
| `src/data/profiles/` | **v5d** `cal_2x11_v5d.json` is the operating profile and the **only file in the directory** (`profile_sha8` fc7519cd). Runs at 3.125 kHz; **requires the cooling fan**, which is on the rig's own switch (§10, hardware-rev line). `cal_2x11_v5`, `v5a` and `v5b` were removed from the working tree on 2026-08-13 and live in git history — restore from there if a recording made under one ever needs its geometry re-read. |
| `src/data/targets/targets_v3.csv` | Human-authored target registry, **current**, 27 objects — `pimd_target_check`'s `DEFAULT_REGISTRY_PATH` and what `pimd_classviz` / `pimd_features` use. Human-owned: tooling reads and validates only, never writes. `targets_v1.csv` is retained for reading the 2026-07-23 corpus. ⚠ `targets_v4.csv` is also tracked and is what **`pimd_rawlog` alone** reads (23 rows, different field set); despite the name it is **not** a successor to v3. |
| `src/data/corpora/` | Signature corpora (`gui_signatures_*.csv`).  |
| `src/data/sessions/` | Raw Mode 2 session dumps — self-describing CSV with embedded profile JSON, per-column map, marks and comment tracks; plus rawlog's verbatim `.txt`. Written automatically whenever the stream runs, ~220 KB/min. Untracked and **not reconstructable after the fact.** |
| `src/data/scratch/` | Scratch captures of **unregistered** objects. Never written into `corpora/` — a corpus build hard-errors on an unregistered `target_id` and that guard stays. |
| `References/images/` | Schematics, scope and GUI reference captures (§15 note below). |
| `References/scope/` | Raw scope CSVs, tracked again as of `20260810_bias_mod/` — nine traces (air / brass / steel RHS × three bands, all at 0 cm) plus `plot_bias.py` and `plot_delay.py`. This is the primary evidence behind §2's fill fractions and §7's post-bias measurements, and the one place they can be re-derived. |
| `README.md` | Repository front page — project summary and entry point for a first-time reader. Also carries the **Toolchain & workflow** pipeline diagram and workflow ordering, inherited from the retired `USAGE.md` (2026-08-13); per-app intent and operation now live in each tool's own file header. |
| `TODO.md` | Working task list. Not a spec: nothing here is authoritative over `DESIGN.md`. |
| `CHANGELOG.md` | Running change log — **the source this file is consolidated from**, and where all history and rationale lives. |
| `DESIGN.md` | **This file** — curated snapshot. Do not edit directly outside a consolidation pass (§18). |
| `CLAUDE.md` | AI-agent working brief — how to behave in this repo. Not project facts. |

**Key reference images** (all in `References/images/`): `schematic-v604.jpg` and
`schematic-v604-sheet2.jpg` (rev 6.04 — **does not show the bias resistor**, §14.2) ·
**`bias_mod_delay_plot_20260810.png`** (the current front end: three bands, air / brass / steel with
the §7 fits overlaid) · `6S-pack-discharge-curve.jpg` (§12) · `GUI-steady-state-256-1024.jpg` (the
SoC reference capture) · `warmup-with-8ns-steps.jpg` (why delays snap to the 8 ns grid).

**Pre-bias-mod images, kept as history only:** `lobe_at_amp_input_20260808.png`,
`spanner_fills_the_null_20260808.png` and `decay_model.png` show the front end before 2026-08-10 —
the shape is still the right picture of the mechanism, the **voltages are void** (§7).

---

## 16. Build, run & deploy

No build step for either the PC tools or the firmware. **Always work inside the venv.** Agent
conventions — version bumps, changelog discipline, the "don't edit DESIGN.md" rule — live in
`CLAUDE.md`.

```bash
python3 -m venv .venv && source .venv/bin/activate
pip install -r src/requirements.txt
cd src

python pimd_gui.py        # Mode 1 GUI (filtered telemetry)
python pimd_classviz.py   # Mode 2 visualiser + corpus capture
python pimd_delaycal.py   # delay-calibration sweep / profile authoring
python pimd_rawlog.py     # raw verbatim session logger — ground truth for offline work

# Offline: registry validation (-f is required; there is no default)
python pimd_target_check.py -f data/targets/targets_v3.csv

# Offline: feature-maths acceptance check. NOTE: expectations are hard-coded from
# the 2026-07-23 63-cell analysis, so this FAILs against any other epoch.
python pimd_shape.py --selftest <gui_signatures_targets_*.csv>

# Offline: corpus acceptance checks (exit 1 on any FAIL, so it can gate a capture day).
# NOTE: the v3-corpus FAILs were never diagnosed. Read the table, not the exit code.
python pimd_corpus_check.py data/corpora/<corpus>.csv
```

PC tools connect to `/dev/ttyACMx` @ 115200.

```bash
# Firmware: no build step — copy onto the board, then power-cycle it.
.venv/bin/mpremote connect /dev/ttyACM0 fs cp mcu/pimd_mcu.py :pimd_mcu.py + fs cp mcu/main.py :main.py
# (mpremote reset does not re-enumerate USB reliably — power-cycle.)
.venv/bin/mpremote connect /dev/ttyACM0 repl
```

### Bench-test over a serial terminal (115200)

```
V                     → version / identify (11 fields, §9)
L                     → list profiles
B                     → diagnostic counters (reset-on-read, 9 fields, §9)
Q4  then  G           → Mode 2 streaming, static CLASSIFY_EP profile;  E to stop
*5000,40000,8400,256  then S → Mode 1 streaming (~20/s);  E to stop
A32                   → one raw boxcar average (R record), idle/Mode 1 only
```

---

## 17. Standing measured facts

> Everything here is a *conclusion*, with the epoch it belongs to. The experiments, the reasoning
> and the results that were superseded along the way are in `CHANGELOG.md` — search by date.
> **Any figure taken under a retired profile is epoch-bound** .

| # | Fact | Epoch |
|---|---|---|
| 17.2 | **The front end is two real poles with opposite-sign residues** — τ_fast 1.125 µs, τ_slow 2.270 µs, ζ 1.06 — giving exactly one zero crossing, and it is not ringing. **The shape stands; the 2026-08-08 voltages do not**. | shape current, voltages void |
| 17.3 | **The null responds to metal.** A steel spanner on the coil removes the zero crossing entirely. It is real coil physics, not an amplifier artefact — which is what made biasing it into view worth doing. | current |
| 17.5 | **The null is the best-SNR region on the ladder.** Steel:brass magnitude ratio through the null is 6–8× on every band against 5.8× at sd 30 µs — the same discrimination at **+187 mV instead of +78 mV**, against a noise floor that does not change with delay. | current |
| 17.6 | **A ferrous target adds a genuine slow pole of its own** — τ_s 19.0 µs (100 µs band), 23.4 µs (50 µs) — which air and non-ferrous do not have, and which vanishes on the 10 µs band because a 10 µs pulse barely excites it. | current |
| 17.7 | **The +97 mV bias mod met its design number**: predicted quiescent +111.7 mV, measured +112.8 mV, and air's worst case moved from clipped to **67.2 mV** above the 2.441 mV floor . | current |
| 17.11 | **Board temperature moves the operating point, upward on cooling** — the same cell was 46.7 % railed at 52.5 °C and 100 % railed at 31.5 °C. Which cells are usable is a function of temperature, not a static property of the ladder. *(Qualified 2026-08-12: the **pack** term is weak — ~1 mV/V, see 17.23 — and the DS18B20 is not a sufficient predictor of the operating point, see §3.)* | current |
| 17.14 | **Thermal and supply drift separate by band-magnitude ratio, not by sign** *(corrected 2026-08-12)*. Bulk warm-up moves band 0 **~16× further** than band 1 (−7.6 % vs −0.46 %) and in the **same** direction; a supply shift moves both together within ~1.5× (−0.81 % vs −0.54 % over 2.1 V). Only an **airflow** change splits them by sign (band 0 +3.7 %, band 1 −0.2 %). The earlier opposite-directions sign test (r = +0.99, 7-band epoch) therefore identifies a **cooling change**, not thermal drift in general — and a warm-up would be misread as a supply shift by it. | current |
| 17.16 | **31.25 kHz is a bad rep rate** — an entire band unusable at 31.25 kHz / 9 µs, restored by moving to 25 kHz with the pulse unchanged. Noise followed the rep rate, not the decay alignment. | all |
| 17.21 | **Family is an orientation coordinate, not a material one.** The early-band sign splits by *placement*: 90.9 % accurate transverse, 53.8 % axial. The **late**-band sign — iron-bearing vs non-ferrous — is the robust axis at **97.2 % ungated**. | prev-epoch |
| 17.22 | **The signature is rank 2 in orientation** and the Pasion–Oldenburg two-basis mixing law is confirmed on oblique captures, so orientation becomes a fitted parameter rather than a confound. | prev-epoch |
| 17.23 | **Pack voltage does NOT materially scale the decay** *(corrected 2026-08-12)*. With U1 healthy and the fan fitted, supply sensitivity is **~1 mV/V grid mean** and the operating point moves **−0.8 % over a 2.1 V pack swing** (§3, §12). *(Qualified 2026-08-13: that figure is a **grid mean**, and individual cells depart from it by an order of magnitude. `cal_2x11_v5d` cell 1 moved **10.9 mV/V** on the 100 µs band and 4.5 mV/V on the 10 µs between two air windows at 20.70 → 20.17 V. The grid mean is the right number for whole-signature scaling; it is the **wrong** number for asking whether an individual amplitude anchor still sits on its voltage — §10's anchors do move with the pack. **A figure of 43–51 mV/V citing §12 circulated in profile `notes` from `cal_2x11_v5a` onward; it is withdrawn** — §12 never carried it and no measurement here supports it.)* | current |
| 17.24 | **Forced-air cooling sets the noise floor and the warm-up, and a fixed mount sets repeatability** *(measured 2026-08-13)*. Moving from a loose 38 mm blow-on fan to a permanent 40 mm case extractor took detrended 32-sweep σ from **50.9 → 37.7 µV** at *overlapping* pack voltage, cut run-to-run scatter **6.4 → 2.2 µV**, and changed warm-up from a two-stage soak to a clean single exponential (**10 → ~6 min**). Cooling is a first-order measurement variable, not a thermal-protection detail. | current |

---

## 18. Change Log Consolidation Pass

You are performing a "human-run consolidation pass".
For THIS task only, you are authorised to edit DESIGN.md (the read-only rule is suspended for this
pass).

CHANGELOG.md is the source of truth for everything that has changed since the last consolidation.
For this consolidation only focus on the lines in CHANGELOG.md **above** the marker:
`<!-- Add new entries above this line. Format: ### <file> — v<N> — <short title> -->`

IMPORTANT — the CHANGELOG is NOT in chronological order. Do not replay entries. First determine the
NET CURRENT STATE per file, then synthesise. DESIGN.md is a consolidated snapshot, not a
concatenation.

**DESIGN.md is a working brief, not an archive.** It carries specs, measured values, the protocol,
invariants, current profile and open problems. It does **not** carry narrative: how a result was
reached, what was tried and reverted, or per-version tool history. All of that lives in
CHANGELOG.md and must not be copied back in. When a fact and its story both exist, keep the fact and
cite the epoch. If a section is growing past a screen or two, it is drifting back toward an archive.

Before editing, produce these for my review:
  1. Current version of each file (firmware and each PC tool) as you read them from the CHANGELOG.
  2. An asset mapping table: each existing DESIGN.md asset path → its `References/` target. Flag any
     old reference with no clear match, and any file in `References/` not yet cited anywhere — do
     NOT guess a match.
  3. Which DESIGN.md sections you'll change, and the net change for each (expect at least the
     header/Doc-rev line).
  4. Anything you plan to drop or significantly reword, and any contradictions found.

Preserve policy text, the invariants (§11) and the protocol (§9) verbatim. Bump the Doc-rev line.
**Delete content that is superseded, contradicted, or duplicated from CHANGELOG.md** — but never
delete a measured value that is still valid without saying where it went.

After I approve and you've updated DESIGN.md:
  - Reset CHANGELOG.md by moving the marker to the top of the file.
  - Add a line under the moved marker: `## Archive — consolidated YYYY-MM-DD`

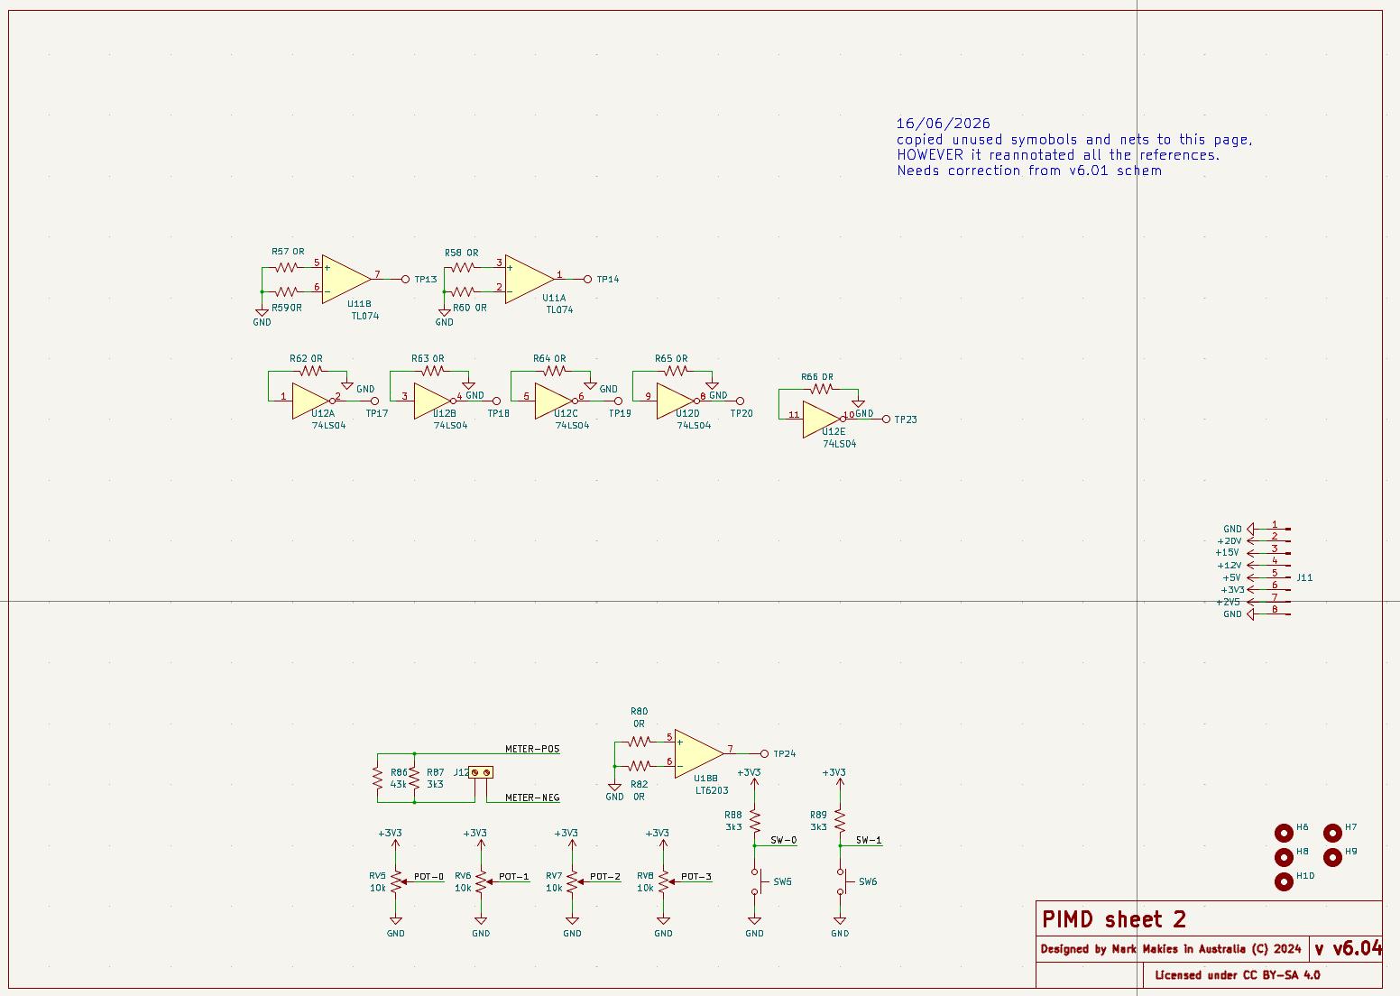
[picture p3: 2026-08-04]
References/images/schematic-v604-sheet2.jpg

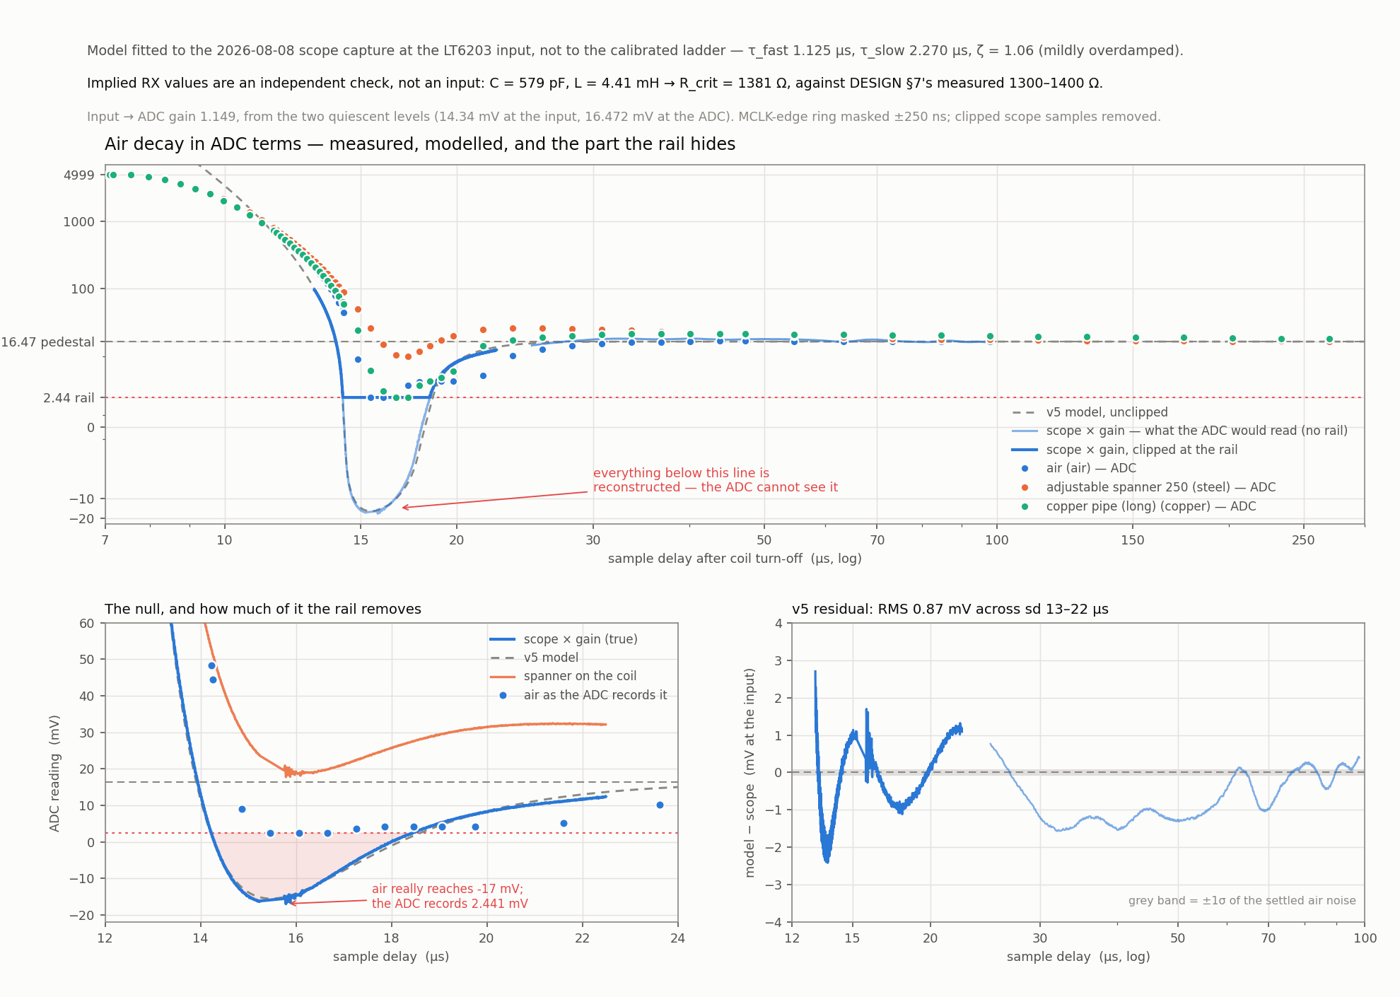
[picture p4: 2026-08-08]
References/images/decay_model.png

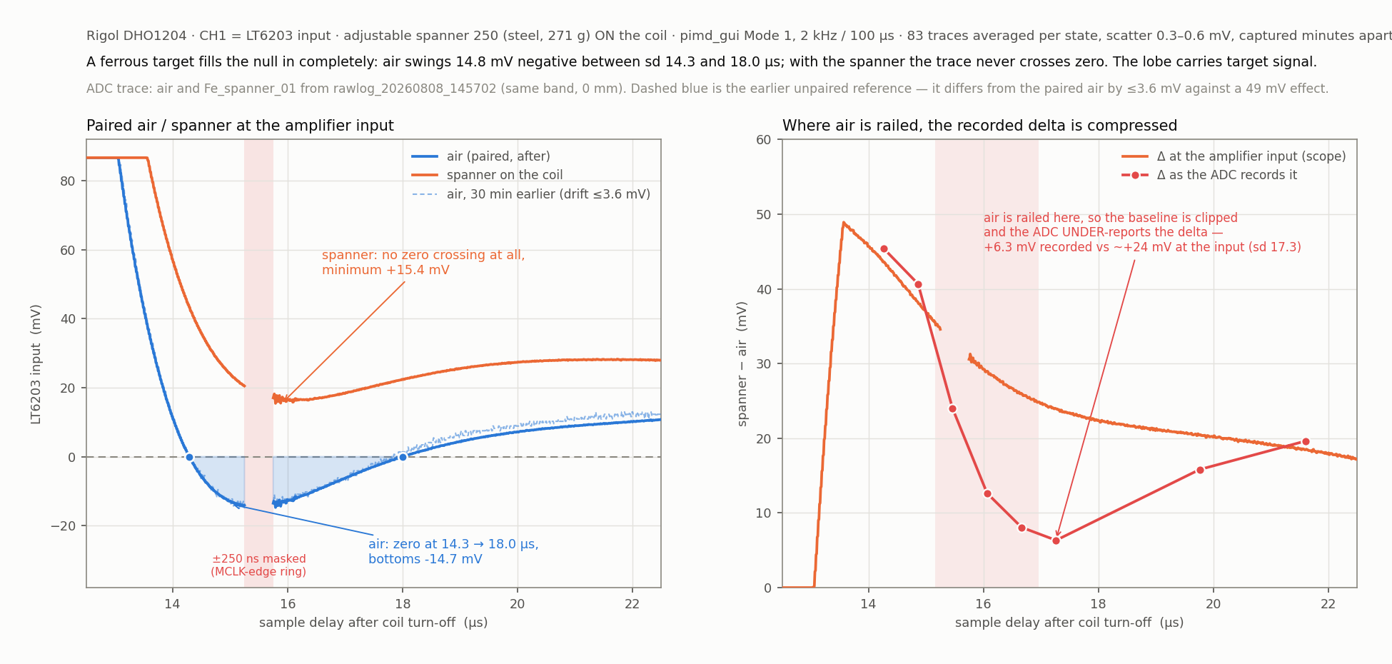
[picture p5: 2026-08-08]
References/images/spanner_fills_the_null_20260808.png

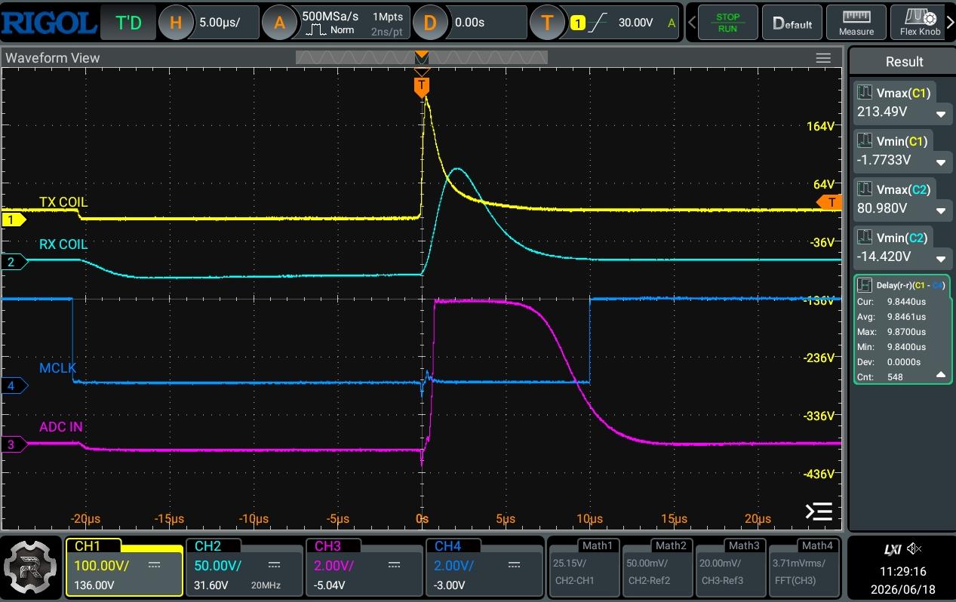
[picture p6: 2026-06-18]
References/images/scope-pulse-baseline.jpeg

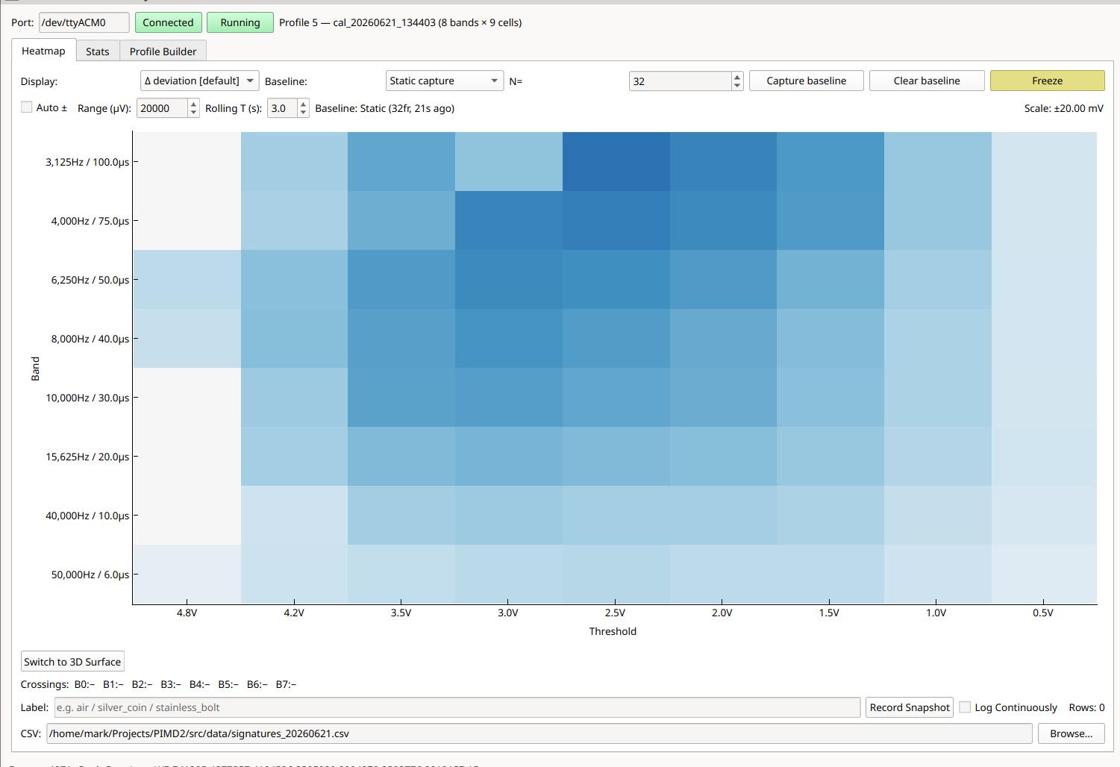
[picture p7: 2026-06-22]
References/images/profile8b-copper-pipe.jpg

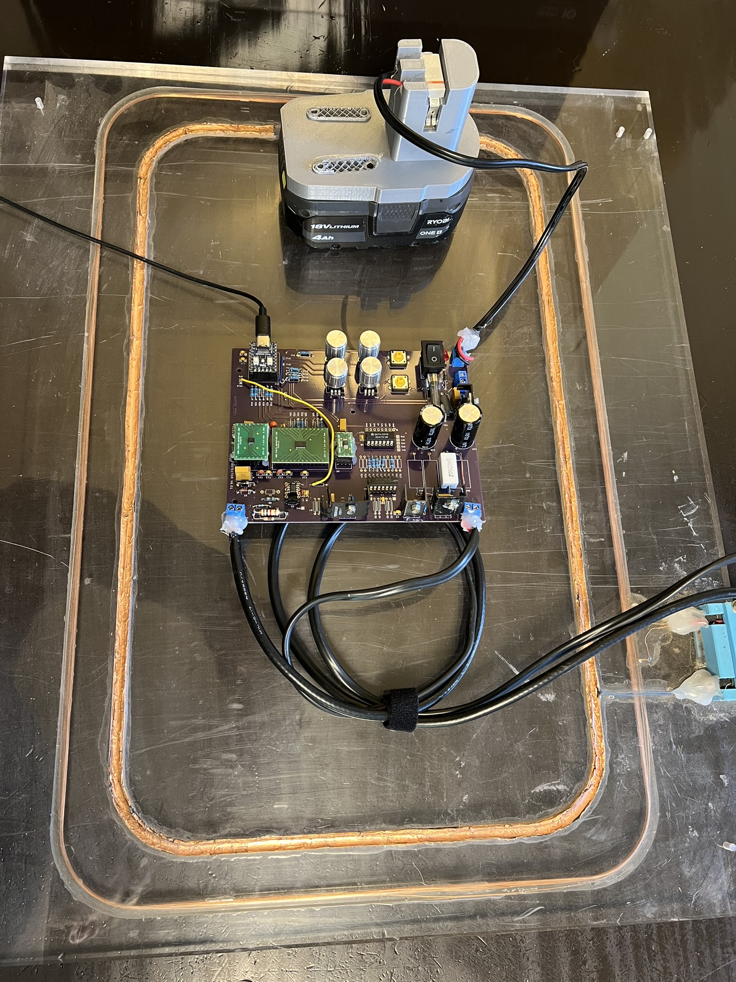
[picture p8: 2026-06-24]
References/images/pcb-coil-baseline.JPEG

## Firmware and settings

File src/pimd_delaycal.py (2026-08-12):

# SPDX-License-Identifier: GPL-3.0-or-later
# Copyright (c) 2022-2026 Mark Makies
# ###############################################################################
# PIMD Delay Calibration v1.49
# Runs on Ubuntu desktop / laptop, standalone PyQt6 app (no .ui file)
#
# For each configured (freq, pulse) pair, sweeps the sample delay from a start
# value in configurable steps, taking an A<n> raw boxcar average at each step,
# and records the (interpolated) delay at which the ADC reading crosses each
# target voltage threshold.  Results are shown in a live-updating table:
#   rows    = freq/pulse pairs  (e.g. "25kHz/10us")
#   columns = target voltages (V)
#   cells   = delay (µs) at threshold crossing, snapped to 8 ns PWM grid (0.008 µs)
#
# Firmware commands used:
#   E                                      — safe state (on connect / stop / done)
#   *<freq_hz>,<pulse_ns>,<delay_ns>,256   — configure PWM (no streaming)
#   A<n>                                   — raw boxcar average; returns R record
#   D<avg>;<freq_hz>,<pulse_us>,<d0>,...;… — define dynamic profile (thermal mode)
#   Q<n>                                   — select profile
#   G                                      — start Mode 2 streaming
#   V                                      — identify; sent once on connect to prime
#                                            the pack / board-temp gauges
#
# Records parsed besides R / W:
#   P<time_ms>,<pack_mV>,<board_temp_dC>   — unsolicited sensor telemetry, ~60 s
#   V<fw>,<board>,…,<pack_mV>,<board_temp_dC>,<lockout>
#   PACK: / LOCKOUT                        — firmware messages, surfaced in the log
#
# board_temp_dC is deci-degrees C (x10 integer) from the DS18B20 on GP6 as of firmware
# v4.33, and TEMP_INVALID_DC (-32768) on that field means NO READING — sensor absent,
# unresponsive or CRC-failing. It is blanked, never logged as a number; see
# _update_sensors(). A calibration is only comparable with another if the conditions
# match (§14.1), so the pack/temperature span across a sweep is recorded in the
# exported profile's notes and in the exported CSV's header block.
#
# History (full detail in CHANGELOG.md):
#   v1.49 pack gauge reads runtime-fraction SoC + live H:MM remaining from the
#         shared pimd_pack.py; the data-quality zone captions are retired
#   v1.48 Manual Nudge cells are type-in editable, not just −/+ steppable
#   v1.47 pack-voltage and board-temperature gauges (P/V telemetry); sweep conditions
#         recorded in the profile notes and the exported CSV header
#   v1.46 calibration table rows pulse-ascending, matching the two thermal tables
#   v1.45 Colour lo/hi: lo spinbox floor -999 mV (was 0), for the signed Mean level metric
#   v1.44 "Mean level" Compare-over-time is now signed with a diverging colour scale, not abs()
#   v1.43 FIX Compare-over-time for "Mean level": was a ratio vs baseline, now an absolute mV delta
#   v1.42 new "Mean level" metric (sustained Compare-over-time); baseline capture logs per-cell values
#   v1.41 FIX misleading "invalid profile index (Q5)"; client-side PWM duty-cycle pre-validation
#   v1.40 FIX Compare-over-time: unsigned ratio, not a signed percentage (_compare_value_ratio)
#   v1.39 Compare-over-time: Space/button capture baseline or rolling-lag %Δ, age-warned Std dev table
#   v1.38 new metric: Max %Δ from mean -- normalises by each cell's own mean, unlike Max |Δ| (mV)
#   v1.37 FIX Std dev table metric jitter (smoothing) + rank-based colouring (Rank vs Absolute)
#   v1.36 Std dev table metric selector (Range P-P, Max |Δ|, Drift ½ vs ½ added); "Samples N" relabel
#   v1.35 guard/status messages now say to press THERMAL for Manual Nudge, not just what not to do
#   v1.34 FIX Auto Nudge running was painting over Manual Nudge; the two modes are now exclusive
#   v1.33 Manual Nudge: rolling-window std gate, continuous gradient colouring, no THERMAL timeout
#   v1.32 compact table rows/font + screen-clamped window geometry (v1.31 no-scroll sizing overshot)
#   v1.31 Manual Nudge: std-dev heatmap colouring + per-cell +/- buttons; no-scroll table sizing
#   v1.30 fine step snapped to the 8 ns grid at default, restore and use (was 100 ns)
#   v1.29 profile save dialog (filename = profile name) + auto-generated notes
#   v1.28 Compare Profiles tab; measured-voltage cache from thermal/Auto soaks
#   v1.27 THERMAL auto-starts on sweep completion (checkbox, default on)
#   v1.26 fine step in ns down to the 8 ns PWM grid (was 10 ns floor, µs)
#   v1.25 APP_VERSION constant re-synced with header (was stuck at 1.19)
#   v1.24 Auto Nudge zigzag respects the signal-detect ceiling (down-only past it)
#   v1.23 sp_auto_max_iter range 1-20 -> 1-100
#   v1.22 Auto Nudge (parallel) locks a channel's delay once it passes threshold
#   v1.21 _auto_nudge_channel log lines prefixed with channel label
#   v1.20 voltage headers to 3 d.p.; Auto Nudge expanding-zigzag from calibrated delay
#   v1.19 Auto Nudge parallel/sequential toggle
#   v1.18 draggable QSplitter between left/right panes
#   v1.17 thermal tables sorted ascending by pulse_us
#   v1.16 row labels: freq in Hz with separator, pulse in µs 1 d.p.
#   v1.15 coarse+fine two-phase sweep per freq/pulse pair
#   v1.14 thermal tables dynamic minimumHeight (all rows visible)
#   v1.13 "Latest delay" label; splitter stretch (1,0); thermal min-height raise
#   v1.12 QSplitter above monitoring; splitter/geometry persistence; unified cell colouring
#   v1.11 post-nudge 1 s settling gate before std-dev accumulation
#   v1.10 wider left column/window; Live Monitoring & Auto Nudge box; settings persistence
#   v1.09 real-time cell colouring during Auto Nudge; Import Profile button
#   v1.08 scrolling activity log; Auto Nudge sequential per-channel
#   v1.07 Auto Nudge: iterative per-cell delay correction
#   v1.06 * command updated to MCU v4.23 protocol (Hz/ns)
#   v1.05 snap threshold-crossing delays to the 8 ns PWM grid; 3 d.p.
#   v1.04 thermal std dev to 2 d.p.
#   v1.03 profile export (classviz JSON) + thermal monitoring mode
#   v1.02 fix double-send bug in _on_r_record/_check_thresholds
#   v1.01 freq and pulse width paired as tuples (e.g. 25/10)
#   v1.00 initial version
###############################################################################

# pyright: reportOptionalMemberAccess=false
# pyright: reportAttributeAccessIssue=false

import json
import os
import sys
import time
from collections import deque
from datetime import datetime
from statistics import stdev as _stdev

os.environ.setdefault('QT_API', 'pyqt6')

from PyQt6.QtWidgets import (  # noqa: E402
    QApplication, QCheckBox, QComboBox, QMainWindow, QWidget, QVBoxLayout,
    QHBoxLayout, QPushButton, QLabel, QDoubleSpinBox, QSpinBox, QLineEdit,
    QTableWidget, QTableWidgetItem, QGroupBox, QFormLayout,
    QFileDialog, QHeaderView, QInputDialog, QPlainTextEdit, QSplitter, QTabWidget,
)
from PyQt6.QtSerialPort import QSerialPort  # noqa: E402
from PyQt6.QtCore import QEvent, QIODevice, QPointF, QRectF, Qt, QTimer  # noqa: E402
from PyQt6.QtGui import QColor, QDoubleValidator, QFont, QPainter, QPen  # noqa: E402

import pimd_pack  # noqa: E402 — pack SoC / time-remaining maths (no Qt in that module)

APP_VERSION = '1.49'

# The PWM period quantum. Every delay the firmware can actually produce is a
# multiple of this, so a sweep step that is not is a step the hardware rounds
# for you -- silently, and not always the same way. v1.26 moved the fine step
# onto this grid; v1.30 stopped the default and the settings restore from
# taking it back off (the default shipped at 100 ns, which is 12.5 steps).
PWM_GRID_NS   = 8
FINE_STEP_DEFAULT_NS = 96      # nearest on-grid value to the old 100

DYNAMIC_PROFILE_INDEX = 5   # matches pimd_mcu.py NUM_PROFILES / pimd_classviz.py
PROFILES_DIR  = os.path.join(os.path.dirname(os.path.abspath(__file__)),
                             'data', 'profiles')
SETTINGS_PATH = os.path.join(os.path.dirname(os.path.abspath(__file__)),
                             'data', 'delaycal_settings.json')

# Row-height budget shared by all three live tables (delay, mean, std dev) so
# none of them ever needs an internal scrollbar. Deliberately compact -- three
# full tables plus the config/log/Auto+Manual Nudge controls all have to fit
# in one non-scrolling window, so every row is a small font on a fixed 20 px
# section (_compact_table() below), not Qt's ~30 px default.
TABLE_HEADER_PX = 20
TABLE_ROW_PX    = 20
TABLE_BORDER_PX = 4
TABLE_MIN_H_PX  = 64
TABLE_FONT_PT   = 8

def _table_min_height(n_rows):
    return max(TABLE_HEADER_PX + n_rows * TABLE_ROW_PX + TABLE_BORDER_PX, TABLE_MIN_H_PX)


def _compact_table(tbl):
    """Small font + fixed row/header height, so the Manual Nudge button
    overlay can't grow a row past the size _table_min_height() budgeted for
    it (Qt otherwise sizes a row to its cell widgets' sizeHint, which for a
    QPushButton is taller than the plain-text rows this was tuned against)."""
    font = QFont()
    font.setPointSize(TABLE_FONT_PT)
    tbl.setFont(font)
    tbl.horizontalHeader().setFont(font)
    tbl.horizontalHeader().setFixedHeight(TABLE_HEADER_PX)
    tbl.verticalHeader().setFont(font)
    tbl.verticalHeader().setDefaultSectionSize(TABLE_ROW_PX)
    tbl.verticalHeader().setSectionResizeMode(QHeaderView.ResizeMode.Fixed)


# Mirrors mcu/pimd_mcu.py's compute_pulse_duties()/pulse_duties_valid() exactly
# -- same constants, same integer truncation -- so delaycal can catch a cell
# the firmware would reject *before* ever sending it, rather than discovering
# it via a D-command rejection. Keep these three in lockstep with the
# firmware's copy if either changes (SAMPLE_PULSE_CORRECTION in particular).
PWM_DUTY_SCALING_NUMERATOR   = 2 ** 16
PWM_DUTY_SCALING_DENOMINATOR_NS = 10 ** 9
SAMPLE_PULSE_CORRECTION_US   = 0.904

def _compute_pulse_duties(pulse_us, delay_us, freq_hz):
    pulse_ns = int(pulse_us * 1000)
    delay_ns = int((delay_us + SAMPLE_PULSE_CORRECTION_US) * 1000)
    drive_duty = (pulse_ns * freq_hz * PWM_DUTY_SCALING_NUMERATOR) // PWM_DUTY_SCALING_DENOMINATOR_NS
    sample_duty = drive_duty + (
        (delay_ns * freq_hz * PWM_DUTY_SCALING_NUMERATOR) // PWM_DUTY_SCALING_DENOMINATOR_NS)
    return drive_duty, sample_duty


def _pulse_duties_valid(drive_duty, sample_duty):
    """True iff both duties fit in 16 bits and sample falls strictly after drive."""
    return 0 <= drive_duty <= 65535 and 0 <= sample_duty <= 65535 and sample_duty > drive_duty


def _max_valid_delay_us(pulse_us, freq_hz):
    """Largest delay_us that keeps sample_duty within the 16-bit PWM ceiling
    for this (pulse_us, freq_hz) -- for an operator-facing "how far can I
    push this" figure. None if the pulse width alone already overflows
    drive_duty (no delay, however short, could fix that)."""
    drive_duty, _ = _compute_pulse_duties(pulse_us, 0.0, freq_hz)
    if drive_duty > 65535:
        return None
    max_delay_ns = ((65535 - drive_duty) * PWM_DUTY_SCALING_DENOMINATOR_NS
                     // (freq_hz * PWM_DUTY_SCALING_NUMERATOR))
    return max_delay_ns / 1000.0 - SAMPLE_PULSE_CORRECTION_US


def _snap_8ns(delay_us):
    """Round a delay to the nearest 8 ns RP2040 PWM clock boundary."""
    ns = round(delay_us * 1000)                              # µs → ns, integer
    return (round(ns / PWM_GRID_NS) * PWM_GRID_NS) / 1000   # snap, back to µs


def _snap_step_ns(step_ns):
    """Snap a fine-sweep step onto the PWM grid, rounding DOWN (min one grid
    step). Down rather than nearest because a step is a resolution promise:
    rounding 100 up to 104 sweeps coarser than the operator asked for, while
    96 only costs an extra sample. The spinbox stepper cannot produce an
    off-grid value, but typing and a restored settings file both can -- and
    the migration at _load_settings() is how 100 ns got there in the first
    place (a stored 0.1 µs from the pre-v1.26 µs spinbox)."""
    return max(1, int(step_ns) // PWM_GRID_NS) * PWM_GRID_NS


# Cell background colours
_COL_PENDING      = QColor(200, 220, 255)   # light blue: in progress (calibration sweep)
_COL_DONE         = QColor(143, 240, 164)   # green:      threshold found / auto passed
_COL_NR           = QColor(210, 210, 210)   # grey:       not reached within max delay
_COL_AUTO_FLAGGED = QColor(246, 97, 81)     # red:        still bad after Auto max attempts
_COL_AUTO_QUEUED  = QColor(249, 240, 107)   # yellow:     bad channel queued for nudging
_COL_AUTO_WORKING = QColor(255, 175,  50)   # amber:      channel currently being soaked
_COL_AUTO_DRIFTED = QColor(186, 156, 214)   # lavender:   locked-good channel now reading above
                                             # threshold — frozen, not re-nudged


# --------------------------------------------------------------------------
# Pack / board-temperature telemetry (v1.47)
#
# The pack maths was duplicated from pimd_gui.py under an "every PC app stands
# alone" rule. That was reversed in v1.49: it now comes from the shared
# pimd_pack.py, because four hand-synced copies of a calibration table is
# exactly the thing that drifts, and the note above telling you to retune all
# three (by then four) apps was the tell. The rule still stands for
# _build_d_command, which is wire formatting rather than a calibration.
#
# Gone with it: the PACK_ZONES "data-quality window", whose captions told the
# operator to sweep only inside a narrow band of pack voltage. DESIGN 17.23,
# corrected 2026-08-12, measures that sensitivity at ~1 mV/V -- the operating
# point moves -0.8 % across a 2.1 V pack swing and thermal drift dominates it
# by ~10x -- so the window was advice against an effect that is not there.
# --------------------------------------------------------------------------

TEMP_GAUGE_MAX_C = 80.0         # board-temp gauge full scale
TEMP_INVALID_MAX_DC = -10_000   # board_temp_dC at or below this is the firmware's
                                # "no reading" sentinel (fw v4.33 sends -32768).
                                # Threshold, not equality -- see pimd_gui.py.

# Telemetry older than this has stopped arriving: the firmware's own cadence is
# ~60 s, so three missed reports mean the board went quiet, not that it is slow.
SENSOR_STALE_S = 180.0


class NudgeCellEdit(QLineEdit):
    """The delay readout inside a Manual Nudge cell overlay — a line edit rather
    than a label, so a delay can be typed straight in as well as stepped with
    the −/+ buttons.

    Frameless and transparent so the QTableWidgetItem's std-dev heat colour
    still shows through (the overlay only occludes the item visually; the item
    stays the single source of truth). Escape or a rejected value reverts to
    the item's text via the revert callback, so a half-typed number can never
    be left standing as if it had been applied."""

    def __init__(self, text, commit, revert, parent=None):
        super().__init__(text, parent)
        self._commit = commit
        self._revert = revert
        self.setFrame(False)
        self.setAlignment(Qt.AlignmentFlag.AlignCenter)
        self.setValidator(QDoubleValidator(0.0, 1e6, 3))
        self.setStyleSheet(
            'QLineEdit { background: transparent; border: none; padding: 0px; '
            'margin: 0px; font-size: %dpt; }'
            'QLineEdit:focus { background: palette(base); '
            'border: 1px solid palette(highlight); }' % TABLE_FONT_PT)
        self.editingFinished.connect(self._on_editing_finished)

    def focusInEvent(self, event):
        super().focusInEvent(event)
        # Deferred: a click-to-focus places the caret after focusInEvent, which
        # would undo an immediate selectAll().
        QTimer.singleShot(0, self.selectAll)

    def keyPressEvent(self, event):
        if event.key() == Qt.Key.Key_Escape:
            self._revert()
            self.clearFocus()
            return
        super().keyPressEvent(event)

    def focusOutEvent(self, event):
        # editingFinished only fires when the validator calls the text
        # acceptable, so an empty or half-typed entry would otherwise be left
        # on screen looking like a set value. Put the cell's real value back.
        if not self.hasAcceptableInput():
            self._revert()
        super().focusOutEvent(event)

    def _on_editing_finished(self):
        # Fires on Return and on focus-out alike; the commit callback decides
        # whether the value is acceptable and reverts the text if not.
        self._commit(self.text())


class BatteryGauge(QWidget):
    """Battery-icon pack gauge — fill and text are state of charge, the caption
    is the measured pack voltage and the time left at the present rate."""

    def __init__(self, parent=None):
        super().__init__(parent)
        self.setMinimumSize(170, 52)
        self.setMaximumHeight(52)
        self._pack_mV = None
        self._lockout = False
        self._tracker = None
        self.setToolTip(
            'Pack voltage from the firmware (P/V telemetry, fw v4.28+).\n'
            'Fill and % are state of charge as the fraction of usable pulsing\n'
            'runtime left, zeroed on the {0:.1f} V firmware floor.\n'
            'The caption is measured volts, then time left at the discharge\n'
            'rate fitted over the last {1:.0f} minutes of pulsing.\n'
            'A leading ~ means no rate has been fitted yet, so the figure is\n'
            'the stored curve ({2}) rather than this pack.'.format(
                pimd_pack.PACK_TRIP_MV / 1000.0,
                pimd_pack.PackTracker.WINDOW_S / 60.0,
                pimd_pack.PACK_CAL_EPOCH))

    def set_reading(self, pack_mV, lockout=False, tracker=None):
        self._pack_mV = pack_mV
        self._lockout = lockout
        self._tracker = tracker
        self.update()

    def paintEvent(self, event):
        p = QPainter(self)
        p.setRenderHint(QPainter.RenderHint.Antialiasing)
        w, h = self.width(), self.height()
        cap_h = 15
        body = QRectF(1.5, 1.5, w - 9.5, h - cap_h - 4)
        nub = QRectF(body.right() + 1.5, body.top() + body.height() * 0.30,
                     5.0, body.height() * 0.40)

        outline = QColor('#5e5c64')
        p.setPen(QPen(outline, 1.5))
        p.setBrush(Qt.BrushStyle.NoBrush)
        p.drawRoundedRect(body, 3.0, 3.0)
        p.setPen(Qt.PenStyle.NoPen)
        p.setBrush(outline)
        p.drawRoundedRect(nub, 1.5, 1.5)

        inner = body.adjusted(3.0, 3.0, -3.0, -3.0)
        soc = pimd_pack.pack_soc_pct(self._pack_mV)
        if soc is not None:
            colour = (pimd_pack.soc_colour(0.0) if self._lockout
                      else pimd_pack.soc_colour(soc))
            p.setBrush(QColor(colour))
            p.drawRect(QRectF(inner.left(), inner.top(),
                              inner.width() * max(0.0, min(100.0, soc)) / 100.0,
                              inner.height()))
            text = '{0:.0f} %'.format(soc)
            sub = pimd_pack.pack_caption(self._pack_mV, self._lockout, self._tracker)
        else:
            text, sub = '—', 'no pack reading'

        font = QFont()
        font.setPointSize(11)
        font.setBold(True)
        p.setFont(font)
        p.setPen(QColor('#241f31'))
        p.drawText(body, Qt.AlignmentFlag.AlignCenter, text)

        font.setPointSize(8)
        font.setBold(False)
        p.setFont(font)
        p.setPen(QColor('#f66151') if self._lockout else self.palette().windowText().color())
        p.drawText(QRectF(0, h - cap_h, w, cap_h),
                   Qt.AlignmentFlag.AlignCenter, sub)


class BarGauge(QWidget):
    """Plain horizontal bar gauge with its reading printed inside — used for
    board temperature."""

    def __init__(self, vmax, fmt, colour='#a8c8e8', parent=None):
        super().__init__(parent)
        self.setMinimumSize(170, 24)
        self.setMaximumHeight(24)
        self._vmax = vmax
        self._fmt = fmt
        self._colour = colour
        self._value = None

    def set_value(self, value):
        self._value = value
        self.update()

    def paintEvent(self, event):
        p = QPainter(self)
        p.setRenderHint(QPainter.RenderHint.Antialiasing)
        body = QRectF(1.5, 1.5, self.width() - 3.0, self.height() - 3.0)
        p.setPen(QPen(QColor('#5e5c64'), 1.5))
        p.setBrush(Qt.BrushStyle.NoBrush)
        p.drawRoundedRect(body, 3.0, 3.0)

        inner = body.adjusted(2.5, 2.5, -2.5, -2.5)
        if self._value is None:
            text = '—'
        else:
            frac = max(0.0, min(1.0, self._value / self._vmax))
            p.setPen(Qt.PenStyle.NoPen)
            p.setBrush(QColor(self._colour))
            p.drawRect(QRectF(inner.left(), inner.top(),
                              inner.width() * frac, inner.height()))
            text = self._fmt.format(self._value)

        font = QFont()
        font.setPointSize(9)
        font.setBold(True)
        p.setFont(font)
        p.setPen(QColor('#241f31') if self._value is not None
                 else self.palette().windowText().color())
        p.drawText(body, Qt.AlignmentFlag.AlignCenter, text)
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

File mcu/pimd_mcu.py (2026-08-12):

# SPDX-License-Identifier: GPL-3.0-or-later
# Copyright (c) 2022-2026 Mark Makies
###############################################################################
# Pulse Induction Metal Detector, v4.37, coil v4
# Runs on RP2040 dev board (Waveshare RP2040-Zero, MicroPython)
#
# Interfaces to LTC2508-32 ADC:
#   SPI1 / filtered 32-bit (SDOA/SCKA/DRL, GPIO8/10/9)  — Mode 1
#   SPI0 / raw 14-bit     (SDOB/SCKB/BUSY, GPIO0/2/15)  — Mode 2
#   1-Wire / DS18B20 board temperature (DQ, GPIO6)      — both modes, v4.33
#
# Mode 1  — filtered/interrupt-driven acquisition
#   S/s  start streaming '*' telemetry
#   E/e  stop (shared with Mode 2)
#   *<freq_hz>,<pulse_ns>,<delay_ns>,<downsample>  configure
#   output: *<time_ms>,<value_uV>,<stddev_uV>,<freq_hz>,<pulse_ns>,<delay_ns>,<downsample>
#   rate: pulse_freq / downsample (e.g. ~20/s at 5 kHz / 256)
#
# Mode 2  — raw interleaved moving-average sweep (see PROFILES table)
#   Q<n>  select profile n (default 0); n == DYNAMIC_PROFILE_INDEX selects the
#         RAM-only profile last defined by D (see below)
#   G/g   start streaming 'W' telemetry
#   E/e   stop (shared)
#   D<averages>;<freq_hz>,<pulse_us>,<d1>,<d2>,...;<freq_hz>,<pulse_us>,<d1>,...;...
#         define the dynamic profile (RAM only, lost on reset). All bands must have
#         the same number of delays. Select it afterwards with Q<DYNAMIC_PROFILE_INDEX>.
#   output: W<profile_idx>,<time_ms>,<mean_ch0>,<mean_ch1>,...
#   rate: min(100 Hz, profile_freq / (n_pulses * n_delays))
#
# Other commands (both modes):
#   A<n>  acquire N boxcar-averaged raw samples at held config (Mode 1 or idle only)
#         -> R<time_ms>,<mean_uV>,<std_uV>,<n>,<freq_hz>,<pulse_ns>,<delay_ns>,<min_uV>,<max_uV>
#   V/v/? identify -> V<fw>,<board_id>,<num_profiles>,<active_idx>,<freq_hz>,<pulse_ns>,<delay_ns>,<downsample>,
#                     <pack_mV>,<board_temp_dC>,<pack_voltage_lockout>
#         (v4.28 appends the three trailing sensor/lockout fields. Additive: no parser
#         in src/ splits V by field count, so this breaks no consumer.)
#   L     list profiles -> one L<idx>,<freq_hz>,<n_pulses>,<n_delays>,<averages>,<name> line each
#   B/b   diagnostic counters, reset on read (9 fields since v4.37)
#         -> B<busy_high_count>,<overrun_count>,<emit_block_count>,<emit_block_ms_max>,
#            <gate_reject_count>,<gate_reprime_count>,
#            <busy_timeout_count>,<busy_spin_min_left>,<rail_absent_ms_max>
#         emit_block_* (v4.27) count Mode 2 emits whose print() blocked longer than
#         EMIT_BLOCK_WARN_MS — i.e. the host stopped draining USB CDC. Non-zero means
#         the sweep was paused and the rig's thermal load changed with it.
#         gate_* (v4.35) count outlier-gate rejections and the re-primes that bound
#         them. Rejections without re-primes = the gate catching glitches; re-primes
#         tracking the signal = the gate fighting real signal (see OUTLIER_GATE_FRAC).
#         busy_timeout_count (v4.37) counts abandoned samples — did a rail loss
#         happen at all. busy_spin_min_left is how close a HEALTHY spin came to
#         BUSY_SPIN_LIMIT (resets to the limit, not 0): small means the cap is too
#         tight and a false abort is coming. rail_absent_ms_max is the longest
#         outage dwell. busy_high_count freezes when BUSY stops, so near-zero
#         alongside a non-zero busy_timeout_count means the outage spanned the
#         whole read window.
#   (unsolicited, both modes) pack-voltage / board-temp telemetry, every SENSOR_REPORT_MS:
#         -> P<time_ms>,<pack_mV>,<board_temp_dC>
#         Both fields are REAL calibrated readings: pack_mV since v4.29 (22k/2k7
#         divider on GP26, see PACK_VOLTAGE_FULLSCALE_MV), board_temp_dC since v4.33
#         (DS18B20 1-Wire sensor on GP6, factory-calibrated to ±0.5 °C).
#         board_temp_dC is deci-degrees C (x10 integer), and TEMP_INVALID_DC (-32768)
#         means NO READING — sensor absent, not responding, or CRC-failing. A consumer
#         must blank its display on that value, never plot it. It cannot collide with a
#         real reading: the DS18B20's range is -55..+125 °C, i.e. -550..+1250 dC.
#   (v4.28) LOW-VOLTAGE FAILSAFE: if pack_mV <= PACK_VOLTAGE_TRIP_MV for
#         PACK_VOLTAGE_TRIP_CONSECUTIVE consecutive samples, firmware forces a stop,
#         disables drive, and LATCHES — S/G/D are rejected until a physical power-cycle.
#         No serial command can clear the latch (deliberate: see CHANGELOG v4.28).
#   (v4.31) PACK-ABSENT SUSPEND: below PACK_ABSENT_MV the rail is off and the MCU is
#         running on USB, so there is no pack to protect — the failsafe suspends instead
#         of latching, and releases when a pack returns at >= PACK_REARM_MV. Lets the
#         pack be switched off or swapped without a physical MCU reset, and lets the
#         board be USB-powered for programming with the pack switched on later.
#         Still not a serial re-arm: it requires the pack to physically go and a
#         healthy one to come back.
#   (v4.37) RAIL-LOSS ABORT: the Mode 2 BUSY poll is bounded by BUSY_SPIN_LIMIT. If
#         the ADC stops converting — typically the +20V rail switched off while the MCU
#         stays alive on USB — the sweep aborts instead of spinning with IRQs masked,
#         which used to take USB CDC down with it and silence the board completely,
#         including the 'PACK: rail absent' the failsafe was supposed to print.
#         Firmware then rests in state 'rail_absent': drive safe, pack/temp telemetry
#         unaffected, Mode 2 resuming by itself once the pack returns at >=
#         PACK_REARM_MV for RAIL_RESUME_CONSECUTIVE checks. A BUSY timeout with the
#         pack reading HEALTHY is a different fault and stops instead ('ADC:' line).
#         S and A<n> are refused while the rail is absent — their read paths still
#         have the unbounded wait (chunks 2 and 3).
#
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

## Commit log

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2026-06-15 Task 4 step 1: add SCOPE_CAL profile + reject P<n> while S running
    Bumps FW to 3.03. Adds Profile 2 (SCOPE_CAL): 5kHz, 10us pulse, the
    same 8 log-spaced delays as CLASSIFY, x=1 (single raw sample per
    delay) for oscilloscope-correlated timing checks - no new
    validate/run/M<idx> logic needed, the Task 3 machinery is already
    generic over any z*y*x grid.
    Also rejects P<n> with Command Input ERROR while S telemetry is
    running, since processing a profile mid-stream left the board
    unresponsive (DRL wait never returns) - caller must send E first.
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2026-06-16 v4.00: two-mode firmware, raw path live, PIMD604 electronics
    Firmware (mcu/pimd_mcu.py, v4.00):
    - Complete serial protocol rewrite: Mode 1 (filtered/interrupt-driven, unchanged
    behaviour) + Mode 2 (raw interleaved moving-average sweep, Q/G/E commands,
    W-record streaming at ≤100 Hz)
    - Raw SPI path (SPI0/SDOB) now live — was dead code in v3.x; metal detection
    response confirmed 2026-06-16 with profile TRACK_25K (25 kHz, 1 cell, x=16)
    - Profiles compiled in: FAST_TRACK, CLASSIFY, SCOPE_CAL, TRACK_25K
    - Removed P<n> one-shot command (caused PWM ping-pong when polled); replaced by
    Q<n> + G streaming model that holds PWM config continuously
    - main.py reduced to one-line launcher: impor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
    [PIMD601.kicad_sch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]
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2026-06-17 fw v4.04–v4.05: fix Mode 2 band-boundary SDOB corruption; prime-ish CLASSIFY_EP freqs
    v4.04: acquire_mode2() read SDOB before pwm.freq() at band boundaries. When
    frequency increases the RP2040 shrinks the PWM WRAP register; if the running
    counter exceeds the new WRAP it wraps immediately, generating a spurious MCLK
    edge that starts a new ADC conversion and overwrites the previous cell result.
    Affected d8 of P0–P3 in CLASSIFY_EP (all increasing-freq boundaries); the
    decreasing-freq wrap-around at i=0 was immune. Fix confirmed on bench.
    v4.05: CLASSIFY_EP band frequencies updated from round numbers to prime-ish
    actuals (10601/17599/29201/43003/56992 Hz) matching the §17.1 equal-power
    swe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
    [pimd_mcu.py]
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2026-06-19 fw v4.21 / classviz v1.07: mitigate 32-frame rolling-buffer ADC spike anomalies
    8 events confirmed in quiet 45-channel Mode 2 recording: all exactly 32 frames
    (M=32 rolling-buffer depth), perfectly flat level shift = one bad raw sample.
    Two root causes (both triggered by USB CDC IRQs in the BUSY-poll/SPI gap):
    Type 1 — SDOB bit-truncation (~50% of true): IRQ delays SPI past next MCLK,
    partial new conversion shifts into the read, producing half/quarter values.
    Type 2 — Cell-value bleed (value > normal): IRQ starves BUSY-high poll long
    enough to miss the current cell's MCLK; lands on previous cell's SDOB output.
    Fix 1 (primary, fw): wrap BUSY poll + SPI read in disable_irq/enable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
    [pimd_mcu.py]
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2026-06-21 delaycal v1.17: thermal monitoring tables sorted ascending by pulse_us
    Latest mean and Std dev rows now display shortest-delay band first.
    _rebuild_thermal_tables() stores _thermal_display_order / _thermal_proto_to_display;
    _update_thermal_tables() uses display row d for item access and protocol band b
    for channel data; _auto_color_cell() routes calibration table colour by b and
    thermal table colour by d so Auto Nudge highlighting stays correct.
    Calibration table row order unchanged.
    [pimd_delaycal.py]
2026-06-21 delaycal v1.18: draggable left/right splitter
    Replace fixed-420px left column with a horizontal QSplitter so the
    activity log and config panel can be resized by dragging the handle.
    Removed setFixedWidth(420) from cfg_box and log_box_grp; left_w gets
    setMinimumWidth(300). h_splitter state persisted in settings alongside
    the existing vertical splitter.
    [pimd_delaycal.py]
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2026-06-21 delaycal v1.19: fix missing QCheckBox import
    [pimd_delaycal.py]
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2026-06-22 Repo cleanup cont.: remove KiCad 3D libs/footprints/gerbers, old References, trim .gitignore
    Removes large bundled KiCad RPi Pico library files (3D models, footprints, gerbers) and
    old mfg outputs that are no longer needed in the repo. References/ images and PDFs removed
    (renamed/relocated). .gitignore trimmed: dropped KiCad backup/cache, PyInstaller, and
    data-log exclusions; added MM-NOTES.md as private. Deleted obsolete src/pimd111_ui.py and
    old cheatsheet; minor version bumps in active firmware and PC tools.
    [PIMD604-B_Cu.gbl, PIMD604-B_Mask.gbs, PIMD604-Edge_Cuts.gm1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]
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2026-07-03 delaycal: zigzag Auto Nudge, per-channel locking, higher iteration cap
    Bundles v1.20-v1.23 (already logged in CHANGELOG.md): Auto Nudge now
    follows an expanding zigzag from the calibrated delay instead of walking
    cumulatively in one direction; parallel mode locks a channel's delay
    permanently on first pass instead of re-nudging it if std later drifts;
    log lines are prefixed per-channel for readability with multiple
    channels nudging at once; and the max-iterations cap raised 20->100 since
    Sequential mode's per-channel attempts needs more room at small nudge
    steps. Voltage column headers also show 3 decimal places.
    [pimd_delaycal.py]
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2026-07-03 Lock cal_72_air_v2 as operating profile; consolidate DESIGN.md
    New profile: geometric pulse ladder (6->100us, x1.5/step) x geometric
    amplitude thresholds (4.2->0.5V, x0.766/step), replacing the linear
    cal_profile_8b ladder. All 72 cells passed calibration (1 delay nudged
    +40ns). PROFILE_cal_72_air_v2.md documents the band plan, threshold
    ladder, calibrated delays and the 4.2V (not 4.5/4.8V) anchor decision.
    DESIGN.md consolidation pass (doc rev 1.6): records the profile switch,
    the 31.25kHz->25kHz rep-rate fix, non-exponential decay across the
    sample window, ~5 min Mode 2 warm-up, and first 7-target session
    findings (steel sign-crossover, mixture superposition). README updated
    to match (thr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
    [frames_20260619_181237.csv, frames_base1.csv, stats_20260618_164856.csv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]
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2026-07-13 fw v4.24: time-floor Mode 2 boundary settling (fix first-column noise)
    BOUNDARY_PRIME settled band boundaries in PWM periods, so 25/20 kHz bands
    got only 600/750 us of real settling vs the ~1ms+ the energy-step
    transient needs. First cell of each band rode a partially-decayed
    transient -> noisy first heatmap column regardless of calibrated
    voltages, wandering on a seconds scale via the 32-deep rolling average.
    Band 1's first cell was rescued by accident by the ms-scale W-record
    print at i==0. New SETTLE_FLOOR_US=3000 floors every boundary (incl the
    band8->band1 wrap) to >=3ms; sweep refresh 289 -> ~301 ms.
    [pimd_mcu.py]
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2026-07-13 Land PC-tool updates: classviz v1.30, delaycal v1.24, features v5, classify/corpus tools
    Code corresponding to the changelog entries archived in the 2026-07-13
    consolidation: classviz v1.17-v1.30 (Analysis tab, Training Session tab,
    Std Dev heatmap mode, top-bar Load & Run, group-mean normalize fix);
    delaycal v1.20-v1.24 (3-d.p. headers, zigzag Auto Nudge with ceiling
    latch and lock-on-pass); features v1-v5 (session-CSV feature extractor,
    L2-norm amplitude convention); new pimd_classify.py v1.2 (live/replay
    Mode 2 classifier) and pimd_corpus_check.py v1.3 (corpus acceptance
    checks); pimd_v2_findings.py v1.0 replaces pimd_knn_baseline.py and
    pimd_pca_explore.py (removed). requirements.txt add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
    [pimd_delaycal.py]
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2026-07-14 fw v4.25: outlier-gate absolute floor — fixes latched small-signal cells
    The v4.21 plausibility gate thresholded on mean_raw // 10 with signed
    raw14: near-zero means floor the gate to 0 and negative means make it
    negative, so every sample is rejected and the substituted mean latches
    the cell at its warm-up value forever. Seen as the last cell of
    cal_72_air_v3 (100µs band, 11.264µs delay) flat at 0 regardless of
    target. Gate now uses abs(mean) with OUTLIER_GATE_MIN = 164 counts
    (~100mV, 1% FS); volts-scale truncation glitches still rejected.
    Needs bench verification after flashing.
    [pimd_mcu.py]
2026-07-14 fw v4.26: hold IRQs across read→CC write; fixes channel-1 σ anomaly
    The W-record print at sweep index 0 leaves USB CDC TX IRQs pending;
    they fired in the gap between cell[0]'s IRQ-protected read and cell[1]'s
    unprotected duty_u16 write, alongside tens of µs of gate/rolling
    interpreter time in the same gap. CC is not double-buffered, so a write
    landing past the wrap left the next conversion sampling at the previous
    cell's compare point — poisoning rolling[1] every sweep. Anomaly was
    locked to sweep position (survived the 6µs→9µs band change) and shows
    as mean bias at positions 0-1 in the v3-era corpus.
    read_raw_bytes_hold() keeps IRQs off from the BUSY-synced read through
    the freq/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
    [pimd_mcu.py]
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2026-07-26 targets_v3 registry + pimd_target_check v4 (-f required, wall 0 = solid)
    New target registry revision src/data/targets/targets_v3.csv: solder roll
    changed, rocks/quartz/water bottle added, existing rows reviewed. The
    LibreOffice export had been written as UTF-7, so every _ - # " and >= arrived
    as a +AF8- style escape; decoded with iconv, content otherwise unchanged.
    Data fixes in the same pass: header typos, a duplicated units cell, a shifted
    Quartz_piece_01 row (dim_c empty with its 40 in wall_thickness), mineral
    material_class for the two rock rows, and Fe_heavy_pully reclassified
    disc -> ring (its 66 mm is a real radial wall on a real bore, so the shape
    was wrong, not the measurement).
    p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
    [targets_v3.csv]
2026-07-28 pimd_classviz v1.51-v1.53: Analysis Trigger Levels gauges + stale-air-reference fix
    Trigger Levels column on the Analysis tab (v1.51): Settle / Detect / Amp / SNR
    bar gauges with draggable threshold markers bound to the Training spinboxes, so
    the auto-detect levels can be set against the live signal instead of guessed at
    and then debugged by running a cycle. Shares the Family Plane's gauge dock via
    _build_gauge_column / _set_gauge rather than cloning it.
    FIX (v1.52): the Detect gauge read ~10 mV in clean air and crept higher against
    a Detect of 0.5 mV that has always worked. _sig_finish_air_trail() never cleared
    _sig_air_ref, so a normal cycle completion left the reference ageing into the
    n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
    [targets_v3.csv]
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2026-07-30 fw v4.27 + classviz v1.64-v1.66 + features v9-v10 + corpus_check v1.8: warm-up findings, host-stall detection, pack-voltage and soak provenance
    Findings from two bench sessions (2026-07-29 pack B 5h20m, 2026-07-30 pack A cold
    start), 151k frames of free air, both captured whole by v1.63's auto-logging:
    - The warm-up transient is confined to the 3.80 V and 4.40 V threshold columns;
    the other seven are flat from the first window to the last. Those 14 cells of
    63 contribute 68-75% of the settle figure while warming.
    - It tracks soak time, not pack state. Matched at 24.05 V AND ~28 min elapsed in
    both sessions, pack A read 1834 uV vs pack B 1036 uV. Over one voltage fall the
    100 us cell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
    [pimd_mcu.py]
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2026-07-31 Std Dev display fixes + two version follow-ups (classviz v1.69, delaycal v1.30, features v14)
    classviz v1.69 — both Std Dev displays bypassed the 64-frame glitch
    substitution and the v1.64 window-span stall guard. The Stats table's
    Mean/Std columns shared both defects and are fixed with the heatmap,
    since their agreeing for the same N is a stated property; they now share
    a single _stddev_window(). New _rolling_disp_buf carries the
    glitch-substituted frames in lockstep with _rolling_buf and _fw_ms_buf,
    so _rolling_buf goes on holding unfiltered raw for the dump and capture
    paths. _window_frames() gains record=False so the heatmap, which redraws
    ahead of the gauges, cannot overwrite the stat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
    [pimd_delaycal.py]
2026-08-03 delaycal: Manual Nudge, selectable metrics, Compare-over-time (v1.31-v1.42)
    Manual Nudge mode: per-cell +/- buttons on the delay table, live std-dev
    heatmap colouring, mutually exclusive with Auto Nudge (was silently painting
    over it), no-scroll compact table sizing.
    Selectable Std dev table metrics (Std dev, Range P-P, Max |delta|, Drift,
    Max %delta, Mean level) with rolling-window smoothing and Rank/Absolute
    colouring, replacing a single hardcoded std-dev reduction.
    Compare-over-time: Space/button-captured baseline or rolling-lag ratio
    against any selected metric, age-warned staleness indicator. Mean level
    added specifically because every spread metric (Std dev/Range/Max delta/
    Drift) se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
    [pimd_delaycal.py]
2026-08-03 delaycal v1.44: Compare-over-time Mean level fixes (v1.43-v1.44)
    v1.43 FIX: Mean level's Compare-over-time value was computed as a ratio
    against baseline (abs(delta)/base), inherited from the other spread
    metrics. That hid large real mV shifts on high-level cells (huge
    denominator) and inflated small ones on already-decayed cells (tiny
    denominator), so which cells lit up tracked each cell's baseline size
    rather than actual target response. Now an absolute mV delta.
    v1.44: the abs() value also collapsed a genuine negative-to-positive
    sign crossing in the target response (early/late-time components of
    opposite sign) into a false "no change" cell, forming a diagonal band
    of misleading zeros ac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
    [pimd_delaycal.py]
2026-08-04 pimd_rawlog.py v1.13: new standalone raw MCU logger for cell-reduction work
    New tool (v1.00-v1.13), independent of pimd_delaycal.py: streams a profile
    and writes every firmware line verbatim to a session log, deliberately
    dumb so it can't develop the display-derived bugs just fixed in delaycal
    v1.43/v1.44. Target/distance picker, Place/Remove markers, settle and
    warm-up indicators, and Resume Session — built out against
    cal_110_full_range_v4.json (10 bands x 11 thresholds) per
    HANDOFF_cell_reduction.md, backed by the new targets_v4.csv registry and
    two new target reference photos.
    Also: cal_110_full_range_v4.json supersedes test v4a-distributted.json
    (geometric delay ladder between the sa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
    [targets_v4.csv]
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2026-08-04 pimd_mcu.py v4.28: pack-voltage + board-temp sense, low-voltage failsafe
    New GP26/GP27 ADC reads for pack voltage and board temperature (placeholder
    linear scales pending the real divider/thermistor hardware), reported every
    60s as an unsolicited P line and bench-testable now via the onboard POT-0/
    POT-1 test pots (schematic sheet 2, added here). Sampled/checked at 1 Hz
    using the same ticks_ms/ticks_diff idiom acquire_mode2 already uses for its
    emit/poll gating -- no new scheduler.
    Adds a hard-latched low-voltage failsafe at the 21.0V working floor: three
    consecutive low readings force a stop and permanently reject S/G/D until a
    physical power-cycle, motivated directly by two 18650 cells ov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
    [pimd_mcu.py]
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2026-08-07 pimd_mcu.py v4.29-v4.32: pack-voltage divider wired, calibrated, failsafe made livable
    Brings the v4.28 pack-sense path from placeholder to working hardware, then fixes
    what wiring it up exposed.
    v4.29 - divider built and calibrated. 22k/2k7 from the +20V rail (J11 pin 2) to
    GP26/ADC0, 1u across the 2k7 and 1k/100n at the pin. +20V is the pack terminal
    voltage: D4 is a shunt reverse-polarity clamp, not a series diode, so there is no
    forward drop to compensate and no drift with load current. FULLSCALE 25000 ->
    30083 mV. The old value was unusable, not merely uncalibrated - full scale sat
    below a charged 6S pack, so a fresh pack pegged exactly where the DESIGN 12
    data-quality ceiling lives, a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
    [pimd_mcu.py]
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2026-08-09 Mode 2: fix the boundary-settle budget, and trace the cell-0 outliers to the emit
    fw v4.34 -- acquire_mode2() measured its band-boundary settle from t0 at the top
    of the loop iteration, so the ~2.3 ms spent at the PREVIOUS cell's configuration
    (dominated by read_raw_bytes_hold()'s BUSY sync) was deducted from this cell's
    budget. Delivered settle was period*settle - (elapsed - period): ~0.6 ms of the
    intended 3 ms at a 25 kHz band. SETTLE_FLOOR_US has never been an absolute floor
    on any band whose period is shorter than the per-cell interpreter time -- i.e.
    every band in every profile. Now measured from t_cfg, the instant the freq/CC
    writes go live. Non-boundary cells unchanged; no invariant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
    [pimd_mcu.py]
2026-08-09 Heatmap/table band order: key on pulse_us, not the first-delay proxy
    All three tools ordered display rows by pulse width, but two of them inferred it
    from bands[i]['delays_us'][0] instead of reading pulse_us. That proxy holds for
    every calibrated profile -- a shorter pulse releases the clamp earlier, so first
    delay and pulse width ascend together -- and classviz v1.70 adopted it having
    verified only cal_110_full_range_v4. It fails the moment two bands are hand-given
    the same delay ladder: cal_3x15_v1 starts both its 50 us and 10 us bands at
    5.160 us, so the tie fell to protocol order and the rows came out 50/10/100
    instead of 10/50/100, on both the Main and Analysis sheets.
    pimd_classviz.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
    [pimd_delaycal.py]
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2026-08-09 Epoch turnover: cal_3x10_v1 is the new corpus starting point, and the previous epoch's tooling retires with it
    cal_3x10_v1 (3 bands x 10 cells = 30 channels, sha8 89590f69) replaces
    cal_63_air_bat_v3 (7 x 9 = 63) as the operating profile. Per band the ladder is 6
    early samples, a skipped span, then 4 late samples -- the first profile here cut
    with the front-end model in hand rather than by sweeping and hoping.
    The skipped span is the null. The front end has two real poles with opposite-sign
    residues, so air has exactly one zero crossing and swings negative; the path is
    unipolar and rails at 2.441 mV, so air is genuinely below the rail for 4.21 us
    (sd 14.23-18.44). DESIGN 14.17 is the conseq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
    [air_wide_20260808.csv, lobe_at_amp_input_20260808_ch1.csv, spanner_vs_air_20260808.csv]
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2026-08-10 cal_3x10_v3 + bench session: the bias mod is fitted and the skip is gone
    Bench session 2026-08-10 with the +97 mV bias resistor fitted (Plan A, 240k
    from 5V-REF into U3A pin 3). Nine scope captures at the LT6203 input -- air,
    brass block, RHS steel tube, across all three bands, targets at 0 cm, 64
    averages. Raw CSVs and both plot scripts in References/scope/20260810_bias_mod/.
    Result: air never goes below 67.2 mV against the old 2.441 mV floor, so the
    whole previously-railed window is live signal on every band. Steel:brass
    magnitude ratio through the null is 6-8x, with 2.4x the amplitude of the late
    cells at 100 us. The null bottom marches earlier with shorter pulse -- 17.52 /
    16.10 / 13.99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
    [100us_air.csv, 100us_brass.csv, 100us_steel_rhs.csv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]
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2026-08-11 delaycal v1.48: type a delay straight into a Manual Nudge cell; cal_3x10_v4 early cells re-cut
    Manual Nudge cell readouts become editable QLineEdits, so reaching a delay far
    from the calibrated one no longer means dozens of -/+ clicks. Typing and
    stepping share one apply path, so a typed value cannot bypass the duty-limit
    refusal.
    cal_3x10_v4 lands with two changes: threshold_v replaced by a plain 5.0 -> 0.5 V
    placeholder countdown (it is an ordering key, not a measurement), and the first
    three delays of every band re-cut out of ADC saturation. The old ladder read a
    flat 8191 codes on cells 0/1 of every band -- a limit, not a measurement --
    which is the constraint the cal_3x10_v3 entry flag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
    [pimd_delaycal.py]
2026-08-11 mcu v4.35: the Mode 2 outlier gate was an absorbing state; cells latched forever
    Root cause of the "stuck early cells" on cal_3x10_v4: the v4.21 plausibility
    gate rejected a sample by substituting the rolling mean AND writing that mean
    back into the ring. That makes "every slot equals the mean" an exact fixed
    point, floor division walks the mean down one code at a time to reach it, and
    once the mean sits further than gate from the true signal every later sample is
    rejected, which is what holds it there. Eleven of thirty channels froze
    bit-identical for 1813 frames in session_20260810_174641.csv, each with a final
    -19 uV step (one raw14 code at averages=32) -- an integer ratchet, not noise.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
    [pimd_mcu.py]
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2026-08-12 mcu v4.36: TEST BUILD — pack floor 21.0 → 19.0 V, re-arm 21.5 → 19.5 V
    Deliberate, temporary divergence from DESIGN §12 so the detector can be
    characterised below the working floor. Revert both constants together
    before any pack that is meant to survive.
    The 21.0 V trip was never a rail limit: at 21.02 V pack the +15 V rail
    still measured 15.20 V on a DMM, flat to 10 mV across a 24.69 -> 21.37 V
    swing, and D4 is a shunt clamp so the L7815 sees the pack directly and
    needs only ~17.2 V in. It is cell protection.
    What it costs is recorded in the source and CHANGELOG: the fitted pack
    has four cells at 3.84 V and a confirmed remaining two at 2.83 V, so at
    a 19.0 V trip the weak pair reac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
    [pimd_mcu.py]
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2026-08-12 mcu v4.37: FIX the unbounded IRQ-off BUSY spin that silenced the board on rail loss
    Switching the +20V rail off while the MCU stayed alive on USB used to
    silence the board completely — no W records, no P telemetry, not even the
    'PACK: rail absent' line the failsafe exists to print. On 2026-08-12 that
    cost a diagnosis: session_20260812_121058 stopped dead at 12:48:55,
    19 minutes before anyone cut the power.
    Mechanism: read_raw_bytes_hold() disabled IRQs then spun on two unbounded
    non-yielding loops; enable_irq() is ~160 lines later. With the ADC
    unpowered, BUSY parks and the MCU spins forever with interrupts globally
    masked, which masks USB CDC too. service_sensors() — the only path to t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
    [pimd_mcu.py]
2026-08-12 pack SoC v1: runtime-fraction gauge with live time remaining, shared by the four tools
    New src/pimd_pack.py replaces the per-cell OCV curve that each PC tool carried
    its own copy of. That curve read a RESTING ICR18650 shape off a LOADED terminal
    voltage and divided by six, which the 2026-08-12 imbalance made meaningless.
    SoC is now the fraction of usable pulsing runtime left, read off a curve of
    loaded volts -> minutes-to-trip and zeroed on PACK_TRIP_MV, so moving the
    firmware floor re-zeros the gauge from one constant. Only the curve's shape
    reaches the percentage.
    Time remaining is fitted live: a least-squares rate over a 15-minute trailing
    window of pack telemetry, projected to the floor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
    [pimd_delaycal.py]
2026-08-12 DESIGN Doc-rev 2.2: full consolidation; the firmware revert-instruction is withdrawn
    Human-run §18 consolidation pass, plus the one source fix it turned up.
    mcu/pimd_mcu.py (comment-only, no version bump): three sites still instructed a
    revert to a 21_000 floor -- PACK_VOLTAGE_TRIP_MV's block, PACK_REARM_MV's block
    and the header lineage's v4.36 line. The 2026-08-12 sweep had already decided
    the opposite and flagged these to be reworded; they were not, so the source was
    telling a future reader to undo a deliberate decision. All three now state the
    floor is settled and the restore instruction is withdrawn. The per-cell
    arithmetic the old warning rested on is not restated -- it came from mea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
    [pimd_mcu.py]
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
